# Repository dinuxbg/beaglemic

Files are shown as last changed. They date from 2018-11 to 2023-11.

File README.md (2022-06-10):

# BeagleMic 16-channel PDM Audio Capture

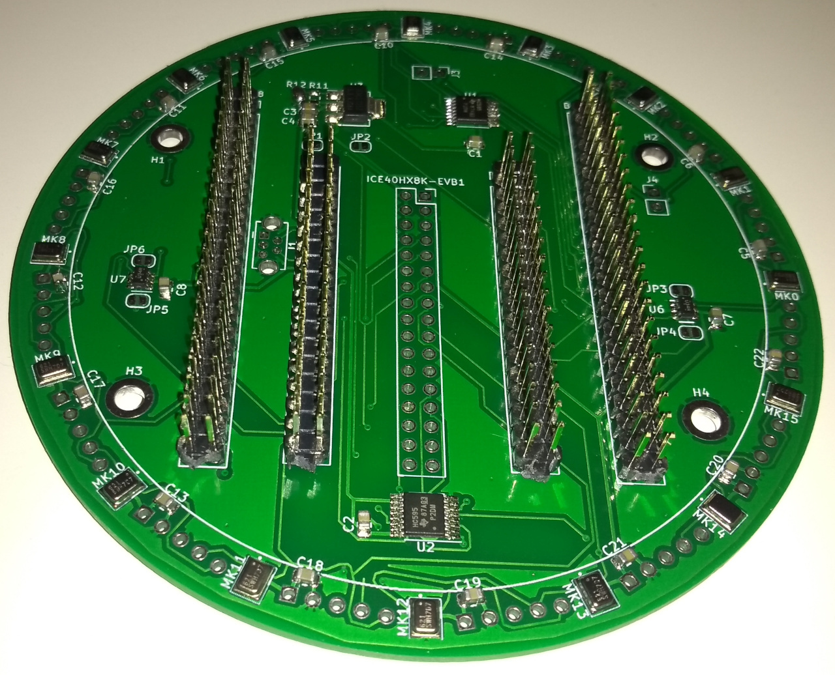
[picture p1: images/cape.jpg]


# Introduction
Ever wanted to record audio from 16 PDM microphones simultanously? Now you can with a BeagleMic running on a [PocketBeagle](https://beagleboard.org/pocket) or [BeagleBone AI](https://bbb.io/ai)

Yes, you could opt for the much simpler I2S microphones. But then you won't have fun writing assembly to capture and process sixteen digital signals at more than 2MHz sample rate.

Audio can be routed to BeagleBone's USB gadget driver. Multichannel audio data can be recorded from a regular PC just as you would record from any other USB microphone. See the section about Buildroot image below.

Current firmware supports:

| Feature | 16 Channel Mode | 8 Channel Mode |
|---|---|---|
| PDM Bit Clock | 2,273 MHz | 3,448 MHz |
| PCM Output Bits Per Sample | 16 bps | 24 bps |
| PCM Output Sample Rate | 31888 Samples/sec | 26940 Samples/sec |

# Freedom
To the best of my knowledge, the entire HW design is Open Hardware and designed with the libre KiCad software. The entire firmware stack is free software, and is built by free toolchains.

Please report any closed components you notice.

# Hardware
The schematic is simple. PDM microphones' digital outputs are connected directly to the PRU input pins. The PRU also drives the bit clock. I have tested on PocketBeagle and BeagleBone AI.

| PocketBeagle | BBAI  | PRU Pin | Type  | Signal |
|---|---|---|---|---|
| P2.24 | P9.11 | R30_14  | Output| PDM Bit Clock |
| P1.36 | P8.44 | R31_0 | Input | MIC0 and MIC1 Data |
| P1.33 | P8.41 | R31_1 | Input | MIC2 and MIC3 Data |
| P2.32 | P8.42 | R31_2 | Input | MIC4 and MIC5 Data |
| P2.30 | P8.39 | R31_3 | Input | MIC6 and MIC7 Data |
| P1.31 | P8.40 | R31_4 | Input | MIC8 and MIC9 Data |
| P2.34 | P8.37 | R31_5 | Input | MIC10 and MIC11 Data |
| P2.28 | P8.38 | R31_6 | Input | MIC12 and MIC13 Data |
| P1.29 | P8.36 | R31_7 | Input | MIC14 and MIC15 Data |

Optionally, high-level software may visualize detected audio direction using a stripe of 16 LEDs hooked to two 74HC595 shift registers:

| PocketBeagle | PB GPIO  | BBAI  | BBAI GPIO | Signal |
|---|---|---|---|---|
| P2.25 | gpio2_9  | P9.30 | gpio5_12  | DS |
| P2.29 | gpio1_7  | P9.28 | gpio4_17  | SHCP |
| P2.31 | gpio1_19 | P9.23 | gpio7_11  | STCP |

For each microphone pair, one microphone is configured to output data on the rising clock edge, and the other is configured to output data on the falling edge. This way we need only 8 input GPIOs to capture data from all 16 microphones.

Microphone breakout board and a PocketBeagle Cape are provided in KiCad format.

Unfortunately the breakout board is essential for a home DIY user like me, since all PDM microphones I could find are BGA. There are numerous youtube guides how to solder BGAs at home using a skillet or a toaster oven.

# Software
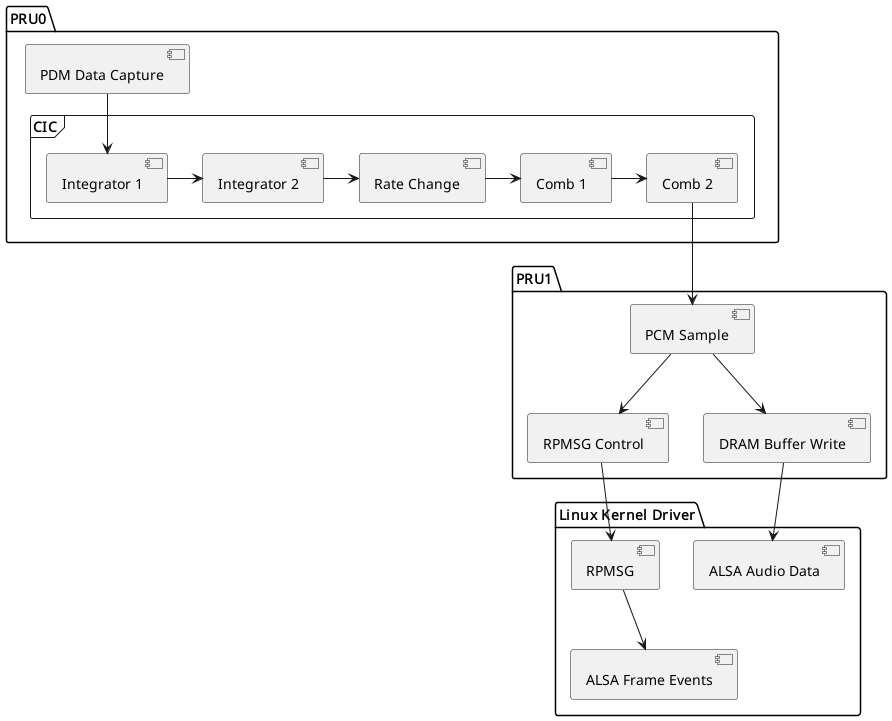
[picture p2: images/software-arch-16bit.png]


PRU0 takes care of driving the PDM bit clock and capturing the microphone bit data. It then runs a CIC filter to convert PDM to PCM, and feeds PCM data to PRU1.

PRU0 has two alternative modes of operation. For 16 channels it executes 2 integrator and 2 comb stages for CIC filtering. Whereas for 8 channels it does 3.

PRU1 is retransmitting PCM data from PRU0 down to the ARM host. RPMSG is used for control commands. Shared DDRAM buffers are used for audio data.

Host audio driver presents a standard ALSA audio card, so that arecord and other standard tools can be readily used.

# Running The Example on PocketBeagle

    # Build kernel module
    sudo apt update
    sudo apt install build-essential linux-headers-`uname -r`
    cd driver
    make
    # Install kernel module
    sudo cp beaglemic.ko /lib/modules/`uname -r`/kernel/drivers/rpmsg/
    sudo depmod -a

    # Load the driver
    sudo modprobe beaglemic

    # Build PRU firmware
    cd pru
    make
    # Start the new PRU firmware
    sudo ./start.sh

    # Record audio
    arecord  -r31888  -c16 -f S16_LE -t wav out.wav
    arecord  -r26940  -c8 -f S32_LE -t wav out.wav
    # Hit Ctrl+C to stop.

# Running The Example on BeagleBone AI

    # Prebuilt DTBO for BB AI is provided in this repo. For corresponding
    # source change, see driver/0001-Initial-BeagleMic-DTS-for-BBAI.patch
    sudo cp driver/am5729-beagleboneai-beaglemic.dtb /boot/dtbs/`uname -r`/
    sudo sed -i -e 's@#dtb=@dtb=am5729-beagleboneai-beaglemic.dtb@g' /boot/uEnv.txt
    sync
    sudo reboot

    # Build kernel module
    sudo apt update
    sudo apt install build-essential linux-headers-`uname -r`
    cd driver
    make
    # Install kernel module
    sudo cp beaglemic.ko /lib/modules/`uname -r`/kernel/drivers/rpmsg/
    sudo depmod -a

    # Load the driver
    sudo modprobe beaglemic

    # Build PRU firmware
    cd pru
    make
    # Start the new PRU firmware
    sudo ./start-bbai.sh

    # Record audio. Use second audio card, since first one is
    # the onboard HDMI.
    arecord -D hw:CARD=BeagleMic -r31888  -c16 -f S16_LE -t wav out.wav
    arecord -D hw:CARD=BeagleMic -r26940  -c8 -f S32_LE -t wav out.wav
    # Hit Ctrl+C to stop.

# Folder Structure

 * beaglemic-cape - Universal cape for BeagleBone AI, PocketBeagle and iCE40HX8K-EVB.
 * driver - Host ALSA audio driver.
 * inmp621-breakout - INMP621 Microphone breakout. Designed to be optionally used with beaglemic-cape.
 * libs - Library code. Currently contains code to drive LED ring for beaglemic-cape.
 * pru - PRU firmware.

# Further Work
A few ideas to improve the design:

 * Move comb filters to PRU1, and try to add more integrators in PRU0.
 * Clean-up the cape PCB.
   * If possible, leave headers for Class-D output from spare PRUs.
 * Migrate to latest kernel 5.10.

# Buildroot Image With USB UAC2 Gadget Mode
The above installation and build instruction steps can be daunting. A [buildroot](https://buildroot.org) configuration for PocketBeagle is available to automate them, and add a bit more.

The buildroot image is small (about 6MB). It initializes the BeagleMic audio driver, and links it to the UAC2 USB Gadget driver. Your BeagleMic PocketBeagle is presented as USB multichannel microphone, so that a regular PC can capture and run desired audio algorithms.

You need to download the beaglemic and buildroot.org GIT trees in separate directories. Then, when building from the buildroot directory you need to provide the beaglemic path via BR2_EXTERNAL environment variable. Example commands:

	git clone --depth=1 git://git.busybox.net/buildroot
	git clone --depth=1 https://gitlab.com/dinuxbg/beaglemic

	cd buildroot
	git checkout 2021.05.3  # Last BR release with kernel 4.19
	export BR2_EXTERNAL=`realpath ../beaglemic/buildroot/`
	make beaglemic_pb_defconfig
	make -j`nproc`

Above should result in a small SDCard image which you can flash. Be sure to get the /dev/sdX right for your SD/MMC card reader.

	sudo dd if=output/images/sdcard.img of=/dev/sdX

When PocketBeagle boots and you connect it via USB to your host, you should be able to record:

	arecord -D hw:CARD=BeagleMic -c8 -t wav -f S32_LE -r24000 out-8ch.wav

## Audio Mode Configuration
Right now UAC2 Gadget is configured only for 8ch/32bps/24000kHz. With a few manual tweaks in buildroot/package/beaglemic-firmware/beaglemicd it can be switched to 16ch/16bps mode. I'm currently researching how I can make this configuration run-time, and how I can control the LED ring via USB.

# References
 * [CIC Filter Introduction](https://dspguru.com/dsp/tutorials/cic-filter-introduction/)
 * [Another CIC Filter Article](http://www.tsdconseil.fr/log/scriptscilab/cic/cic-en.pdf)
 * [Series of PDM articles and software implementations](https://curiouser.cheshireeng.com/category/projects/pdm-microphone-toys/)
 * [Another CIC Filter Article](https://www.embedded.com/design/configurable-systems/4006446/Understanding-cascaded-integrator-comb-filters)
 * [CIC Filter Introduction](http://home.mit.bme.hu/~kollar/papers/cic.pdf)
 * [SPM0423HD4H Datasheet](http://media.digikey.com/PDF/Data%20Sheets/Knowles%20Acoustics%20PDFs/SPM0423HD4H-WB.pdf)
 * [INMP621 Datasheet](https://invensense.tdk.com/download-pdf/inmp621-datasheet/)
 * [Inspiration for high-bandwidth data acquisition](https://github.com/ZeekHuge/BeagleScope)

# Other Resources
Below are various other CIC implementations and PDM microphone boards I've stumbled upon.
 * https://github.com/introlab/16SoundsUSB
 * https://github.com/introlab/odas
 * https://respeaker.io/make_a_smart_speaker/
 * https://github.com/Scrashdown/PRU-Audio-Processing
 * https://github.com/fakufaku/kurodako

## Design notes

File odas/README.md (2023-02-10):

This is a sample configuration for running [ODAS](https://github.com/introlab/odas) with BeagleMic.

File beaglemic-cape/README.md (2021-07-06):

# Beaglemic-Cape

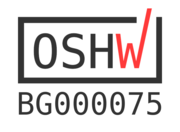
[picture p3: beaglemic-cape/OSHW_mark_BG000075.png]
OSHW


This is a KiCAD project for a 16 PDM Microphone board with host support for:
 * BeagleBone AI
 * PocketBeagle
 * ICE40HX8K-EVB1 (**untested!**)

PDM microphones can either be:
 * Soldered on the cape board, which is not for beginners. You would require a steady hand or pick-and-place machine, and reflow soldering oven.
 * Connected via regular headers using external [breakout](../inmp621-breakout/README.md) [board](https://www.adafruit.com/product/3492).

# Future Improvements

A few ideas for improvements in an eventual future PCB revision:

 * Move the USB OTG connector to the outer edge, so that cable does not interfere with PocketBeagle.
 * Add a few extra LEDs for power and other status.
 * Add better package placement indicators on silkscreen (e.g. first pin, IC dent).
 * Remove the BBAI connector. I couldn't find a way to utilize the proprietary DSPs, so let's focus on USB microphone with PocketBeagle.
 * Switch to bottom-facing LEDs so that all SMD parts are on one of the PCB sides.

# References
 * Microphone footprint, 3D model and schematics symbol are taken from https://www.snapeda.com/parts/INMP621/InvenSense/view-part/?ref=digikey . Footprint has minor modification to "break" the ground track and ease the data wires routing.
 * Freerouting.org was used for routing some of the PCB tracks.

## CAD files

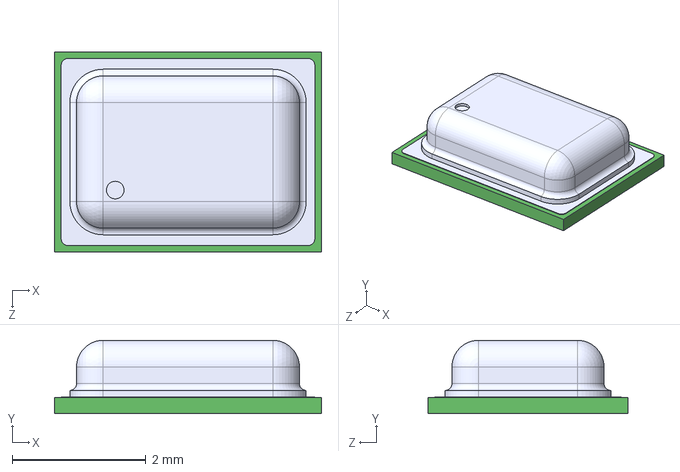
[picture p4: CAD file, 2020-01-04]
beaglemic-cape/INMP621--3DModel-STEP-56544.STEP
4.00 x 1.10 x 3.00 mm

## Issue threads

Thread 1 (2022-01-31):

How to interface I2S mic?

mculla95, 2022-01-31:
Hello

@dinuxbg you mention that interfacing an I2S mic would be much easier, however I am trying to do so but I am having problems. I have a Beaglebone AI and a [TIDA-01454](https://www.ti.com/tool/TIDA-01454) which outputs in I2S. I followed this [guide](https://community.element14.com/challenges-projects/project14/visionthing/b/blog/posts/beaglebone-ai-survival-guide-v3-18-pwm-i2c-analog-digital-read-write-vision-ai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) for pinmuxing and tried to follow [this one](https://www.ti.com/lit/an/sprac97/sprac97.pdf) from TI for the codec. The soundcard is detected however when I try to record i get this error:

```
debian@beaglebone:/var/lib/cloud9$ arecord --device="hw:1,0" -d 20 -f S16_LE test.wav
Recording WAVE 'test.wav' : Signed 16 bit Little Endian, Rate 8000 Hz, Mono
arecord: pcm_read:2145: read error: Input/output error
```

I cant exactly copy the dts file in TI guide because mcasp1_fck isnt defined in Beaglebone AI. So how would I have to interface the codec in the DTS file?

This is my DTS file right now:

```
#include "am5729-beagleboneai.dts"
// make it easy to determine which dtb you're currently running on
// (via /proc/device-tree/chosen/)
/ {
 chosen {
  base_dtb = "am5729-beagleboneai-custom.dts";
  base_dtb_timestamp = __TIMESTAMP__;
 };
};
// eventually these should be available in a header
#define P9_14  (0x3400 + 4 * 107)
#define P9_16  (0x3400 + 4 * 108)
#define P9_19a (0x3400 + 4 * 16)
#define P9_19b (0x3400 + 4 * 95)
#define P9_20a (0x3400 + 4 * 17)
#define P9_20b (0x3400 + 4 * 94)
#define P9_12  (0x3400 + 4 * 171)
#define P9_27b (0x3400 + 4 * 172)
#define P9_18b (0x3400 + 4 * 173)
//
/{

pcm5102a: pcm5102a {
   #sound-dai-cells = <0>;
   compatible = "ti,pcm5102a";
   status = "okay";
};

sound {compatible = "simple-audio-card";
        simple-audio-card,format = "i2s";
        simple-audio-card,name = "PCM5102a";
        simple-audio-card,bitclock-master = <&sound1_master>;
        simple-audio-card,frame-master = <&sound1_master>;
        simple-audio-card,bitclock-inversion;

        simple-audio-card,cpu {
                sound-dai = <&mcasp1>;
        };
        sound1_master: simple-audio-card,codec {
            #sound-dai-cells = <0>;
            sound-dai = <&pcm5102a>;
    
        };
      };
};

// enable i2c-3 on P9.19 (scl) + P9.20 (sda)
&i2c4 {
 status = "okay";
 clock-frequency = <400000>;
 pinctrl-names = "default";
 pinctrl-0 = <&i2c4_pins>;

};

&mcasp1 {
    #sound-dai-cells = <0>;
    status = "okay";
    pinctrl-names = "default";
    pinctrl-0 = <&mcasp1_pins>;
    op-mode = <0>;    /* MCASP_IIS_MODE */
    tdm-slots = <2>;
    num-serializer = <4>;
    /* 16 serializers */
    serial-dir = < /* 1 TX 2 RX 0 unused */
             2 0 0 0
        >;
    rx-num-evt = <1>;
    tx-num-evt = <1>;
};

&dra7_pmx_core {
 i2c4_pins: i2c4 {
  pinctrl-single,pins = <
   DRA7XX_CORE_IOPAD( P9_19a, PIN_INPUT_PULLUP | MUX_MODE7  )  // scl
   DRA7XX_CORE_IOPAD( P9_19b, PIN_INPUT_PULLUP | MUX_MODE14 )  // (shared pin)
   DRA7XX_CORE_IOPAD( P9_20a, PIN_INPUT_PULLUP | MUX_MODE7  )  // sda
   DRA7XX_CORE_IOPAD( P9_20b, PIN_INPUT_PULLUP | MUX_MODE14 )  // (shared pin)
  >;
 };
 mcasp1_pins: mcasp1_pins {
  pinctrl-single,pins = <
   DRA7XX_CORE_IOPAD(P9_12, PIN_INPUT_PULLDOWN | MUX_MODE0) // 12 0  mcasp1_aclkr  BIT CLOCK      BCLK
   DRA7XX_CORE_IOPAD(P9_27b, PIN_INPUT | MUX_MODE0) // 27b 0  mcasp1_fsr    FRAME SYNC            LRCLK
   DRA7XX_CORE_IOPAD(P9_18b, PIN_INPUT | MUX_MODE0) // 18b 0  mcasp1_axr0   I2S INPUT             DATA
  >;
 };
};
// enable pwm-2 on P9.14 (out-A) + P9.16 (out-B)
&epwmss2 {
 status = "okay";
};
&ehrpwm2 {
 status = "okay";
 pinctrl-names = "default";
 pinctrl-0 = <&ehrpwm2_pins>;
};
&dra7_pmx_core {
 ehrpwm2_pins: ehrpwm2 {
  pinctrl-single,pins = <
   DRA7XX_CORE_IOPAD( P9_14, PIN_OUTPUT_PULLDOWN | MUX_MODE10 )  // out A
   DRA7XX_CORE_IOPAD( P9_16, PIN_OUTPUT_PULLDOWN | MUX_MODE10 )  // out B
  >;
 };
};

// Here's the obnoxious part: since u-boot doesn't have same pin defaults yet, all pins not
// explicitly setup above should be overridden here.  This will eventually no longer be needed.
&cape_pins_default {
 pinctrl-single,pins = <
  DRA7XX_CORE_IOPAD( 0x372C, PIN_INPUT_PULLDOWN | MUX_MODE15 ) // P9.11a (no gpio)
  DRA7XX_CORE_IOPAD( 0x3620, PIN_INPUT          | MUX_MODE14 ) // P9.11b
  //DRA7XX_CORE_IOPAD( 0x36AC, PIN_INPUT_PULLDOWN | MUX_MODE14 ) // P9.12
  DRA7XX_CORE_IOPAD( 0x3730, PIN_INPUT_PULLDOWN | MUX_MODE15 ) // P9.13  (no gpio)
 // DRA7XX_CORE_IOPAD( 0x35AC, PIN_INPUT_PULLDOWN | MUX_MODE14 ) // P9.14
  DRA7XX_CORE_IOPAD( 0x3514, PIN_INPUT_PULLDOWN | MUX_MODE14 ) // P9.15
 // DRA7XX_CORE_IOPAD( 0x35B0, PIN_INPUT_PULLDOWN | MUX_MODE14 ) // P9.16
  DRA7XX_CORE_IOPAD( 0x37CC, PIN_INPUT_PULLDOWN | MUX_MODE14 ) // P9.17a
  DRA7XX_CORE_IOPAD( 0x36B8, PIN_INPUT          | MUX_MODE14 ) // P9.17b
  DRA7XX_CORE_IOPAD( 0x37C8, PIN_INPUT_PULLDOWN | MUX_MODE14 ) // P9.18a
  //DRA7XX_CORE_IOPAD( 0x36B4, PIN_INPUT          | MUX_MODE14 ) // P9.18b
 // DRA7XX_CORE_IOPAD( 0x3440, PIN_INPUT_PULLUP   | MUX_MODE14 ) // P9.19a
 // DRA7XX_CORE_IOPAD( 0x357C, PIN_INPUT          | MUX_MODE14 ) // P9.19b
 // DRA7XX_CORE_IOPAD( 0x3444, PIN_INPUT_PULLUP   | MUX_MODE14 ) // P9.20a
 // DRA7XX_CORE_IOPAD( 0x3578, PIN_INPUT          | MUX_MODE14 ) // P9.20b
  DRA7XX_CORE_IOPAD( 0x34F0, PIN_INPUT_PULLDOWN | MUX_MODE14 ) // P9.21a
  DRA7XX_CORE_IOPAD( 0x37C4, PIN_INPUT          | MUX_MODE14 ) // P9.21b
  DRA7XX_CORE_IOPAD( 0x369C, PIN_INPUT_PULLDOWN | MUX_MODE14 ) // P9.22a
  DRA7XX_CORE_IOPAD( 0x37C0, PIN_INPUT          | MUX_MODE14 ) // P9.22b
  DRA7XX_CORE_IOPAD( 0x37B4, PIN_INPUT_PULLUP   | MUX_MODE14 ) // P9.23
  DRA7XX_CORE_IOPAD( 0x368C, PIN_INPUT_PULLUP   | MUX_MODE14 ) // P9.24
  DRA7XX_CORE_IOPAD( 0x3694, PIN_INPUT_PULLDOWN | MUX_MODE14 ) // P9.25
  DRA7XX_CORE_IOPAD( 0x3688, PIN_INPUT_PULLUP   | MUX_MODE14 ) // P9.26a
  DRA7XX_CORE_IOPAD( 0x3544, PIN_INPUT          | MUX_MODE14 ) // P9.26b
  DRA7XX_CORE_IOPAD( 0x35A0, PIN_INPUT_PULLDOWN | MUX_MODE14 ) // P9.27a
  //DRA7XX_CORE_IOPAD( 0x36B0, PIN_INPUT          | MUX_MODE14 ) // P9.27b
  DRA7XX_CORE_IOPAD( 0x36E0, PIN_INPUT_PULLDOWN | MUX_MODE14 ) // P9.28
  DRA7XX_CORE_IOPAD( 0x36D8, PIN_INPUT_PULLDOWN | MUX_MODE14 ) // P9.29a
  DRA7XX_CORE_IOPAD( 0x36A8, PIN_INPUT          | MUX_MODE14 ) // P9.29b
  DRA7XX_CORE_IOPAD( 0x36DC, PIN_INPUT_PULLDOWN | MUX_MODE14 ) // P9.30
  DRA7XX_CORE_IOPAD( 0x36D4, PIN_INPUT_PULLDOWN | MUX_MODE14 ) // P9.31a
  DRA7XX_CORE_IOPAD( 0x36A4, PIN_INPUT          | MUX_MODE14 ) // P9.31b
  DRA7XX_CORE_IOPAD( 0x36A0, PIN_INPUT_PULLDOWN | MUX_MODE14 ) // P9.41a
  DRA7XX_CORE_IOPAD( 0x3580, PIN_INPUT          | MUX_MODE14 ) // P9.41b
  DRA7XX_CORE_IOPAD( 0x36E4, PIN_INPUT_PULLDOWN | MUX_MODE14 ) // P9.42a
  DRA7XX_CORE_IOPAD( 0x359C, PIN_INPUT          | MUX_MODE14 ) // P9.42b
  DRA7XX_CORE_IOPAD( 0x379C, PIN_INPUT_PULLUP   | MUX_MODE14 ) // P8.3
  DRA7XX_CORE_IOPAD( 0x37A0, PIN_INPUT_PULLUP   | MUX_MODE14 ) // P8.4
  DRA7XX_CORE_IOPAD( 0x378C, PIN_INPUT_PULLUP   | MUX_MODE14 ) // P8.5
  DRA7XX_CORE_IOPAD( 0x3790, PIN_INPUT_PULLUP   | MUX_MODE14 ) // P8.6
  DRA7XX_CORE_IOPAD( 0x36EC, PIN_INPUT_PULLDOWN | MUX_MODE14 ) // P8.7
  DRA7XX_CORE_IOPAD( 0x36F0, PIN_INPUT_PULLDOWN | MUX_MODE14 ) // P8.8
  DRA7XX_CORE_IOPAD( 0x3698, PIN_INPUT_PULLDOWN | MUX_MODE14 ) // P8.9
  DRA7XX_CORE_IOPAD( 0x36E8, PIN_INPUT_PULLDOWN | MUX_MODE14 ) // P8.10
  DRA7XX_CORE_IOPAD( 0x3510, PIN_INPUT_PULLDOWN | MUX_MODE14 ) // P8.11
  DRA7XX_CORE_IOPAD( 0x350C, PIN_INPUT_PULLDOWN | MUX_MODE14 ) // P8.12
  DRA7XX_CORE_IOPAD( 0x3590, PIN_INPUT_PULLDOWN | MUX_MODE14 ) // P8.13
  DRA7XX_CORE_IOPAD( 0x3598, PIN_INPUT_PULLDOWN | MUX_MODE14 ) // P8.14
  DRA7XX_CORE_IOPAD( 0x3570, PIN_INPUT_PULLDOWN | MUX_MODE14 ) // P8.15a
  DRA7XX_CORE_IOPAD( 0x35B4, PIN_INPUT          | MUX_MODE14 ) // P8.15b
  DRA7XX_CORE_IOPAD( 0x35BC, PIN_INPUT_PULLDOWN | MUX_MODE14 ) // P8.16
  DRA7XX_CORE_IOPAD( 0x3624, PIN_INPUT_PULLDOWN | MUX_MODE14 ) // P8.17
  DRA7XX_CORE_IOPAD( 0x3588, PIN_INPUT_PULLDOWN | MUX_MODE14 ) // P8.18
  DRA7XX_CORE_IOPAD( 0x358C, PIN_INPUT_PULLDOWN | MUX_MODE14 ) // P8.19
  DRA7XX_CORE_IOPAD( 0x3780, PIN_INPUT_PULLUP   | MUX_MODE14 ) // P8.20
  DRA7XX_CORE_IOPAD( 0x377C, PIN_INPUT_PULLUP   | MUX_MODE14 ) // P8.21
  DRA7XX_CORE_IOPAD( 0x3798, PIN_INPUT_PULLUP   | MUX_MODE14 ) // P8.22
  DRA7XX_CORE_IOPAD( 0x3794, PIN_INPUT_PULLUP   | MUX_MODE14 ) // P8.23
  DRA7XX_CORE_IOPAD( 0x3788, PIN_INPUT_PULLUP   | MUX_MODE14 ) // P8.24
  DRA7XX_CORE_IOPAD( 0x3784, PIN_INPUT_PULLUP   | MUX_MODE14 ) // P8.25
  DRA7XX_CORE_IOPAD( 0x35B8, PIN_INPUT_PULLDOWN | MUX_MODE14 ) // P8.26
  DRA7XX_CORE_IOPAD( 0x35D8, PIN_INPUT_PULLDOWN | MUX_MODE14 ) // P8.27a
  DRA7XX_CORE_IOPAD( 0x3628, PIN_INPUT          | MUX_MODE14 ) // P8.27b
  DRA7XX_CORE_IOPAD( 0x35C8, PIN_INPUT_PULLDOWN | MUX_MODE14 ) // P8.28a
  DRA7XX_CORE_IOPAD( 0x362C, PIN_INPUT          | MUX_MODE14 ) // P8.28b
  DRA7XX_CORE_IOPAD( 0x35D4, PIN_INPUT_PULLDOWN | MUX_MODE14 ) // P8.29a
  DRA7XX_CORE_IOPAD( 0x3630, PIN_INPUT          | MUX_MODE14 ) // P8.29b
  DRA7XX_CORE_IOPAD( 0x35CC, PIN_INPUT_PULLDOWN | MUX_MODE14 ) // P8.30a
  DRA7XX_CORE_IOPAD( 0x3634, PIN_INPUT          | MUX_MODE14 ) // P8.30b
  DRA7XX_CORE_IOPAD( 0x3614, PIN_INPUT_PULLDOWN | MUX_MODE14 ) // P8.31a
  DRA7XX_CORE_IOPAD( 0x373C, PIN_INPUT_PULLDOWN | MUX_MODE15 ) // P8.31b (no gpio)
  DRA7XX_CORE_IOPAD( 0x3618, PIN_INPUT_PULLDOWN | MUX_MODE14 ) // P8.32a
  DRA7XX_CORE_IOPAD( 0x3740, PIN_INPUT_PULLDOWN | MUX_MODE15 ) // P8.32b (no gpio)
  DRA7XX_CORE_IOPAD( 0x3610, PIN_INPUT_PULLDOWN | MUX_MODE14 ) // P8.33a
  DRA7XX_CORE_IOPAD( 0x34E8, PIN_INPUT          | MUX_MODE14 ) // P8.33b
  DRA7XX_CORE_IOPAD( 0x3608, PIN_INPUT_PULLDOWN | MUX_MODE14 ) // P8.34a
  DRA7XX_CORE_IOPAD( 0x3564, PIN_INPUT          | MUX_MODE14 ) // P8.34b
  DRA7XX_CORE_IOPAD( 0x360C, PIN_INPUT_PULLDOWN | MUX_MODE14 ) // P8.35a
  DRA7XX_CORE_IOPAD( 0x34E4, PIN_INPUT          | MUX_MODE14 ) // P8.35b
  DRA7XX_CORE_IOPAD( 0x3604, PIN_INPUT_PULLDOWN | MUX_MODE14 ) // P8.36a
  DRA7XX_CORE_IOPAD( 0x3568, PIN_INPUT          | MUX_MODE14 ) // P8.36b
  DRA7XX_CORE_IOPAD( 0x35FC, PIN_INPUT_PULLDOWN | MUX_MODE14 ) // P8.37a
  DRA7XX_CORE_IOPAD( 0x3738, PIN_INPUT_PULLDOWN | MUX_MODE15 ) // P8.37b (no gpio)
  DRA7XX_CORE_IOPAD( 0x3600, PIN_INPUT_PULLDOWN | MUX_MODE14 ) // P8.38a
  DRA7XX_CORE_IOPAD( 0x3734, PIN_INPUT_PULLDOWN | MUX_MODE15 ) // P8.38b (no gpio)
  DRA7XX_CORE_IOPAD( 0x35F4, PIN_INPUT_PULLDOWN | MUX_MODE14 ) // P8.39
  DRA7XX_CORE_IOPAD( 0x35F8, PIN_INPUT_PULLDOWN | MUX_MODE14 ) // P8.40
  DRA7XX_CORE_IOPAD( 0x35EC, PIN_INPUT_PULLDOWN | MUX_MODE14 ) // P8.41
  DRA7XX_CORE_IOPAD( 0x35F0, PIN_INPUT_PULLDOWN | MUX_MODE14 ) // P8.42
  DRA7XX_CORE_IOPAD( 0x35E4, PIN_INPUT_PULLDOWN | MUX_MODE14 ) // P8.43
  DRA7XX_CORE_IOPAD( 0x35E8, PIN_INPUT_PULLDOWN | MUX_MODE14 ) // P8.44
  DRA7XX_CORE_IOPAD( 0x35DC, PIN_INPUT_PULLDOWN | MUX_MODE14 ) // P8.45a
  DRA7XX_CORE_IOPAD( 0x361C, PIN_INPUT          | MUX_MODE14 ) // P8.45b
  DRA7XX_CORE_IOPAD( 0x35E0, PIN_INPUT_PULLDOWN | MUX_MODE14 ) // P8.46a
  DRA7XX_CORE_IOPAD( 0x3638, PIN_INPUT          | MUX_MODE14 ) // P8.46b
 >;
};
```

dinuxbg, 2022-01-31:
I'm afraid you cannot reuse anything from beaglemic for your project. McASP configuration is rather different from PRU firmware writing.

By "I2S is simpler" I meant that writing PRU firmware for I2S microphones would be simpler than writing PRU firmware for PDM microphones. Still, it would not be trivial.

I would suggest to play with arecord parameters. Try with "-c2" because I2S is stereo.  Drop the "-d" parameter and let ALSA pick a suitable value. Try other rates besides 8000.

Also it might be better to post this question on the Beagleboard forum.

Closed 2022-01-31.

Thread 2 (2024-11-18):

Port driver to latest TI kernel

dinuxbg, 2024-11-18:
The 4.19 kernel currently used is outdated, forcing the usage of old buildroot for building the linux image. Port to latest kernel - RPMSG is hopefully no longer a fast moving target.

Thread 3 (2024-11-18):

Port to PocketBeagle2

dinuxbg, 2024-11-18:
Port software for the upcoming [PocketBeagle2](https://www.beagleboard.org/boards/pocketbeagle-2), since the original PocketBeagle is no longer in stock.

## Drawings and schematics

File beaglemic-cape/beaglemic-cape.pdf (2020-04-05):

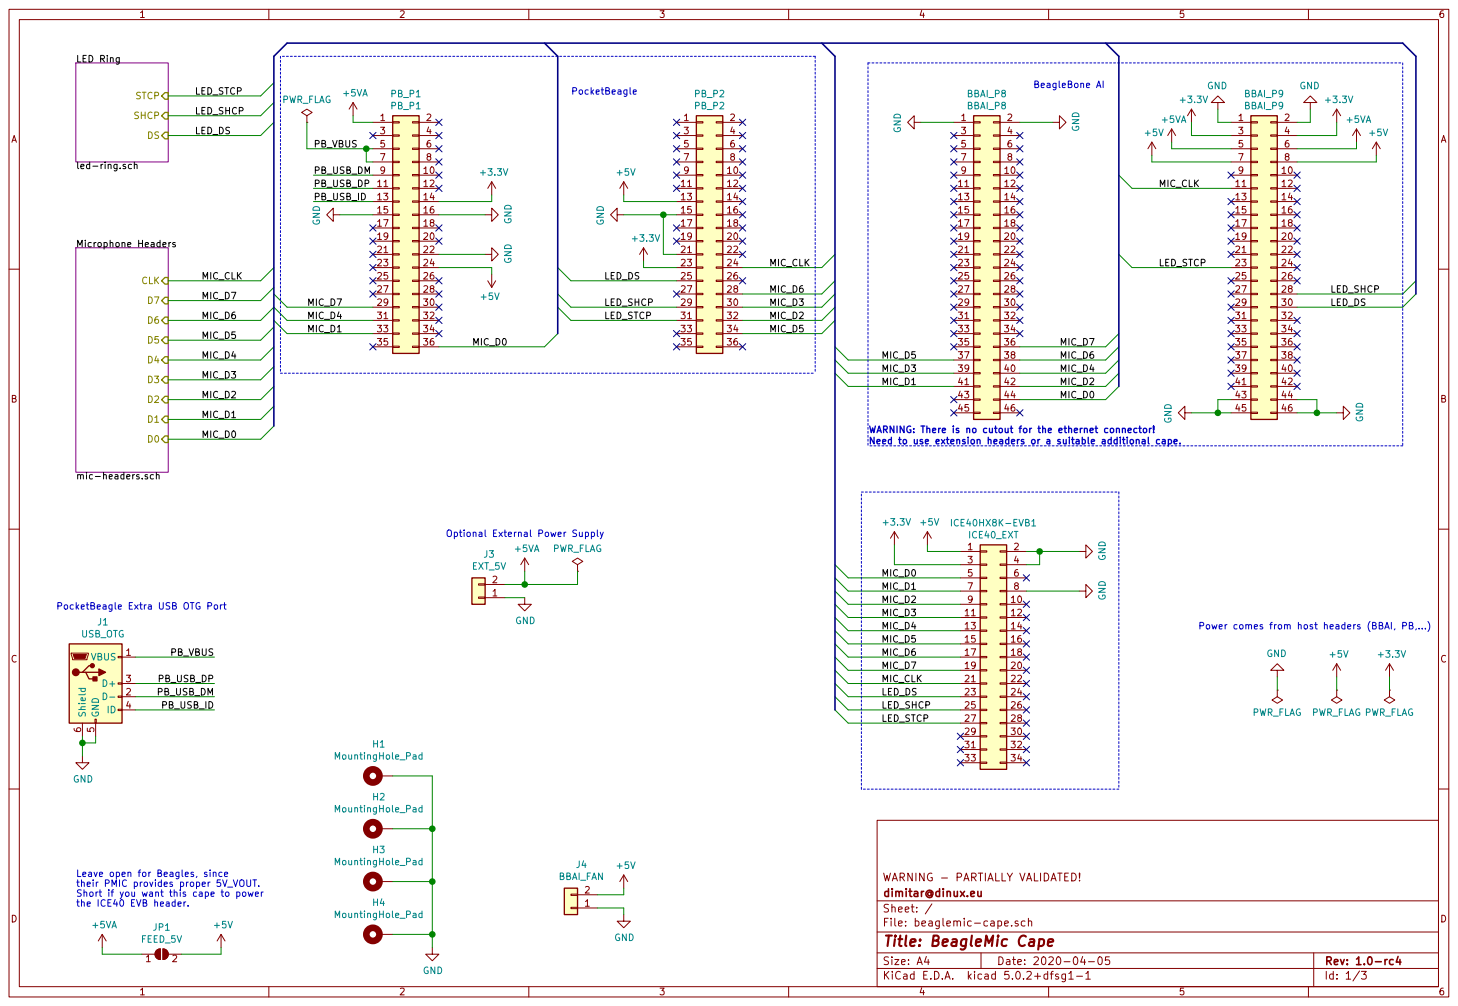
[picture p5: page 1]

Optional External Power Supply +5VA

PocketBeagle Extra USB OTG Port
J1 USB_OTG

Leave open for Beagles, since
their PMIC provides proper 5V_VOUT.
Short if you want this cape to power
the ICE40 EVB header.

File: beaglemic-cape.sch Sheet: / dimitar@dinux.eu WARNING - PARTIALLY VALIDATED!

Id: 1/3 Title: BeagleMic Cape

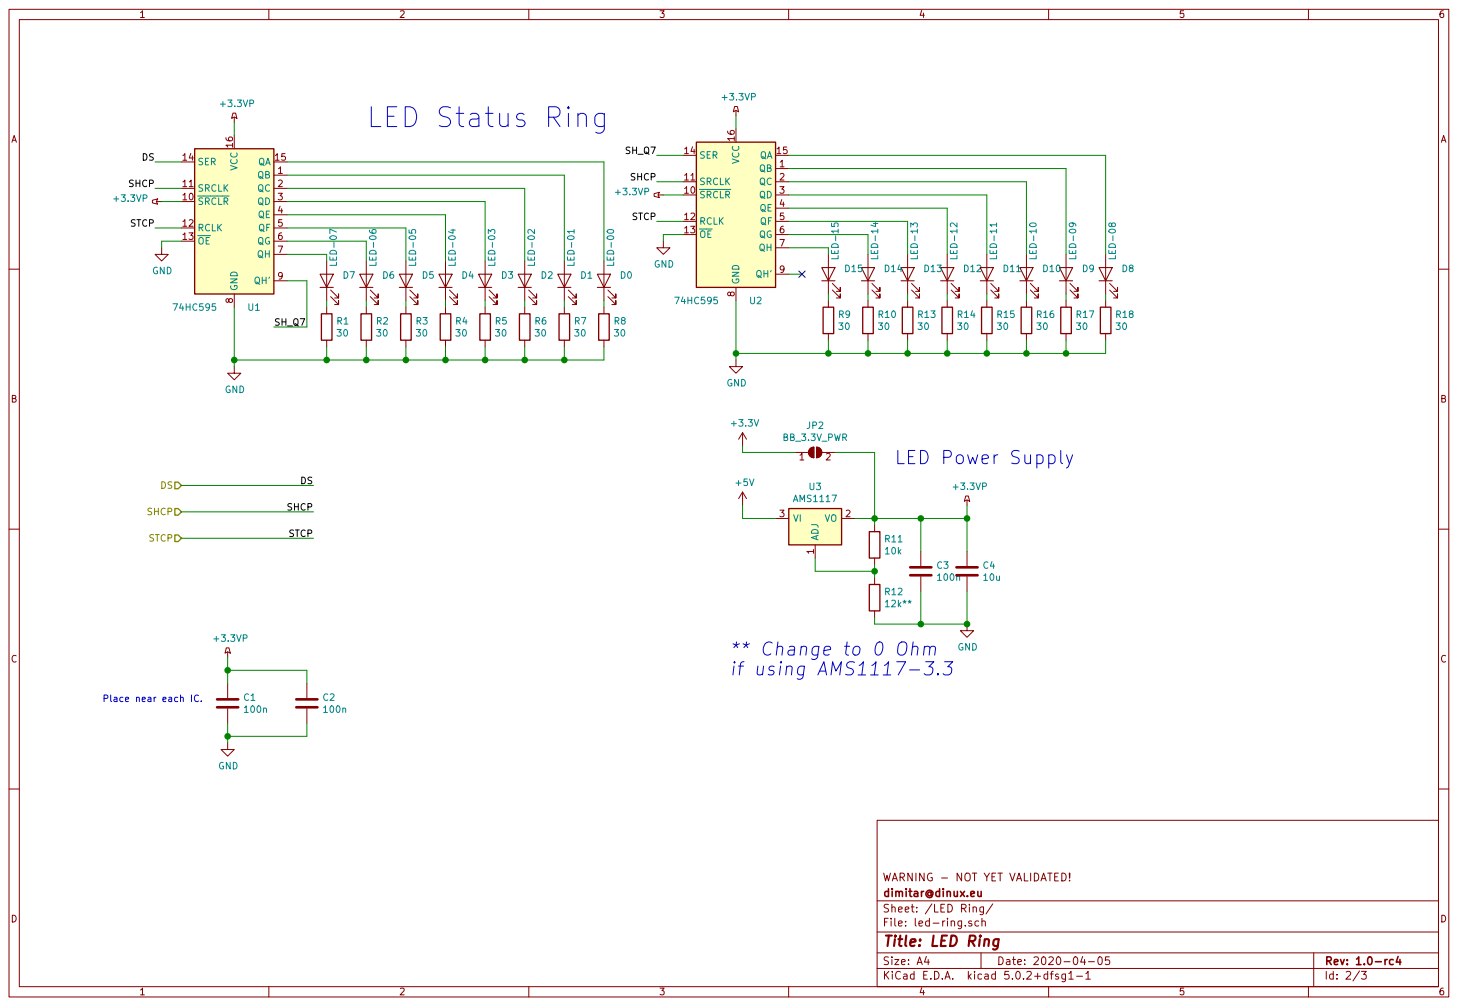
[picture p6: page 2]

dimitar@dinux.eu WARNING - NOT YET VALIDATED!

Sheet: /LED Ring/
File: led-ring.sch
Id: 2/3 Title: LED Ring

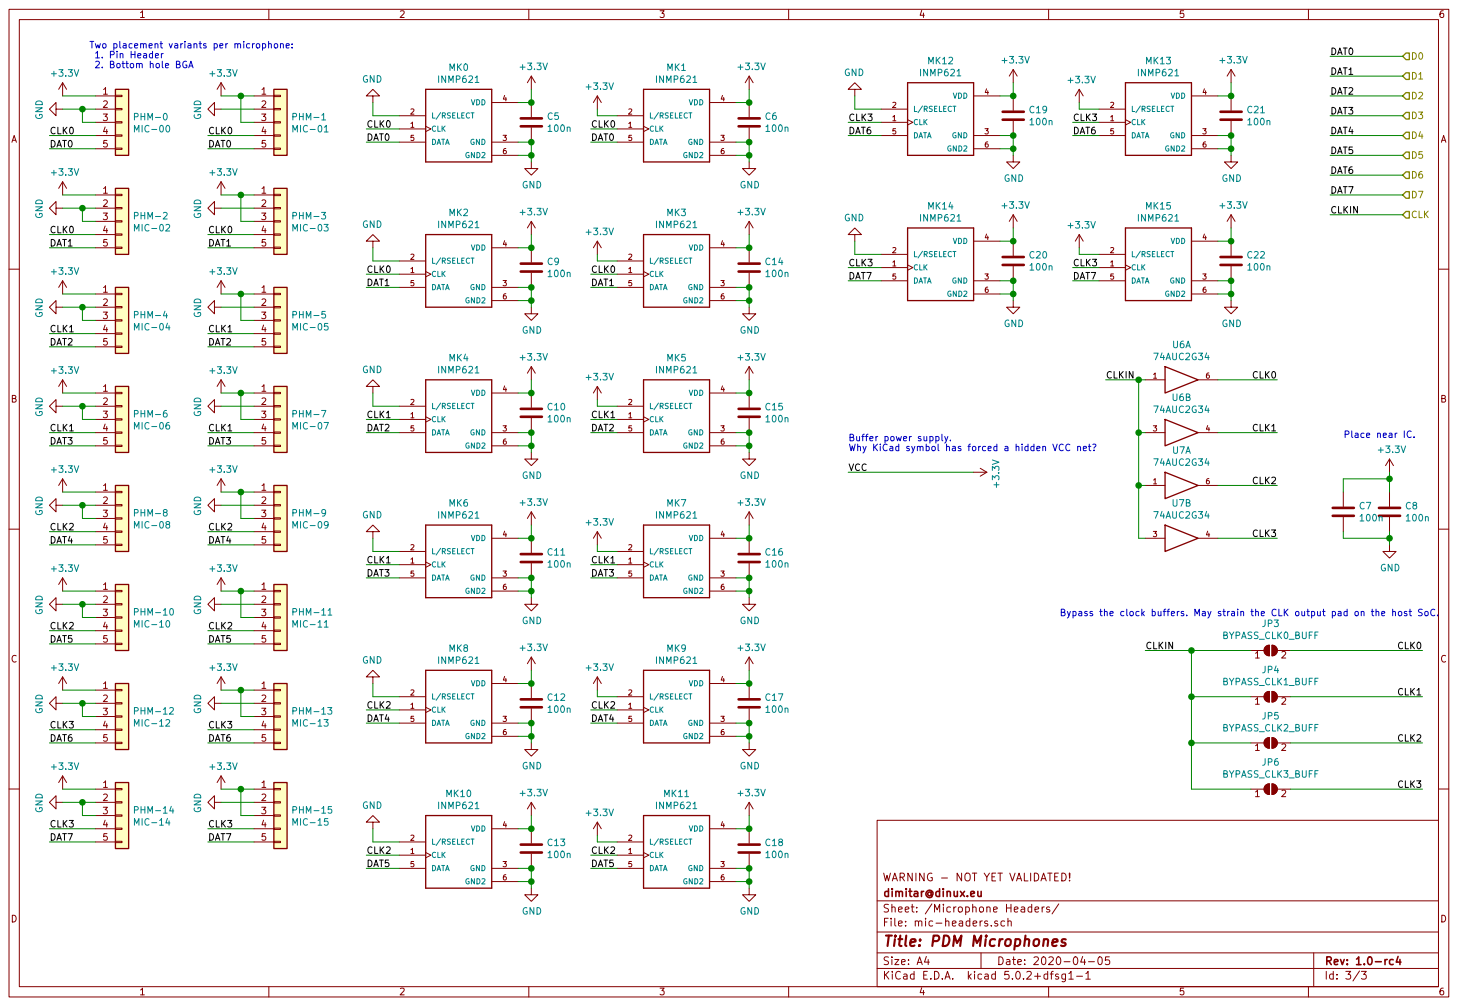
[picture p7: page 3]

Two placement variants per microphone:
1. Pin Header

100n Place near IC. +3.3V GND

File: mic-headers.sch Sheet: /Microphone Headers/
Id: 3/3 Title: PDM Microphones

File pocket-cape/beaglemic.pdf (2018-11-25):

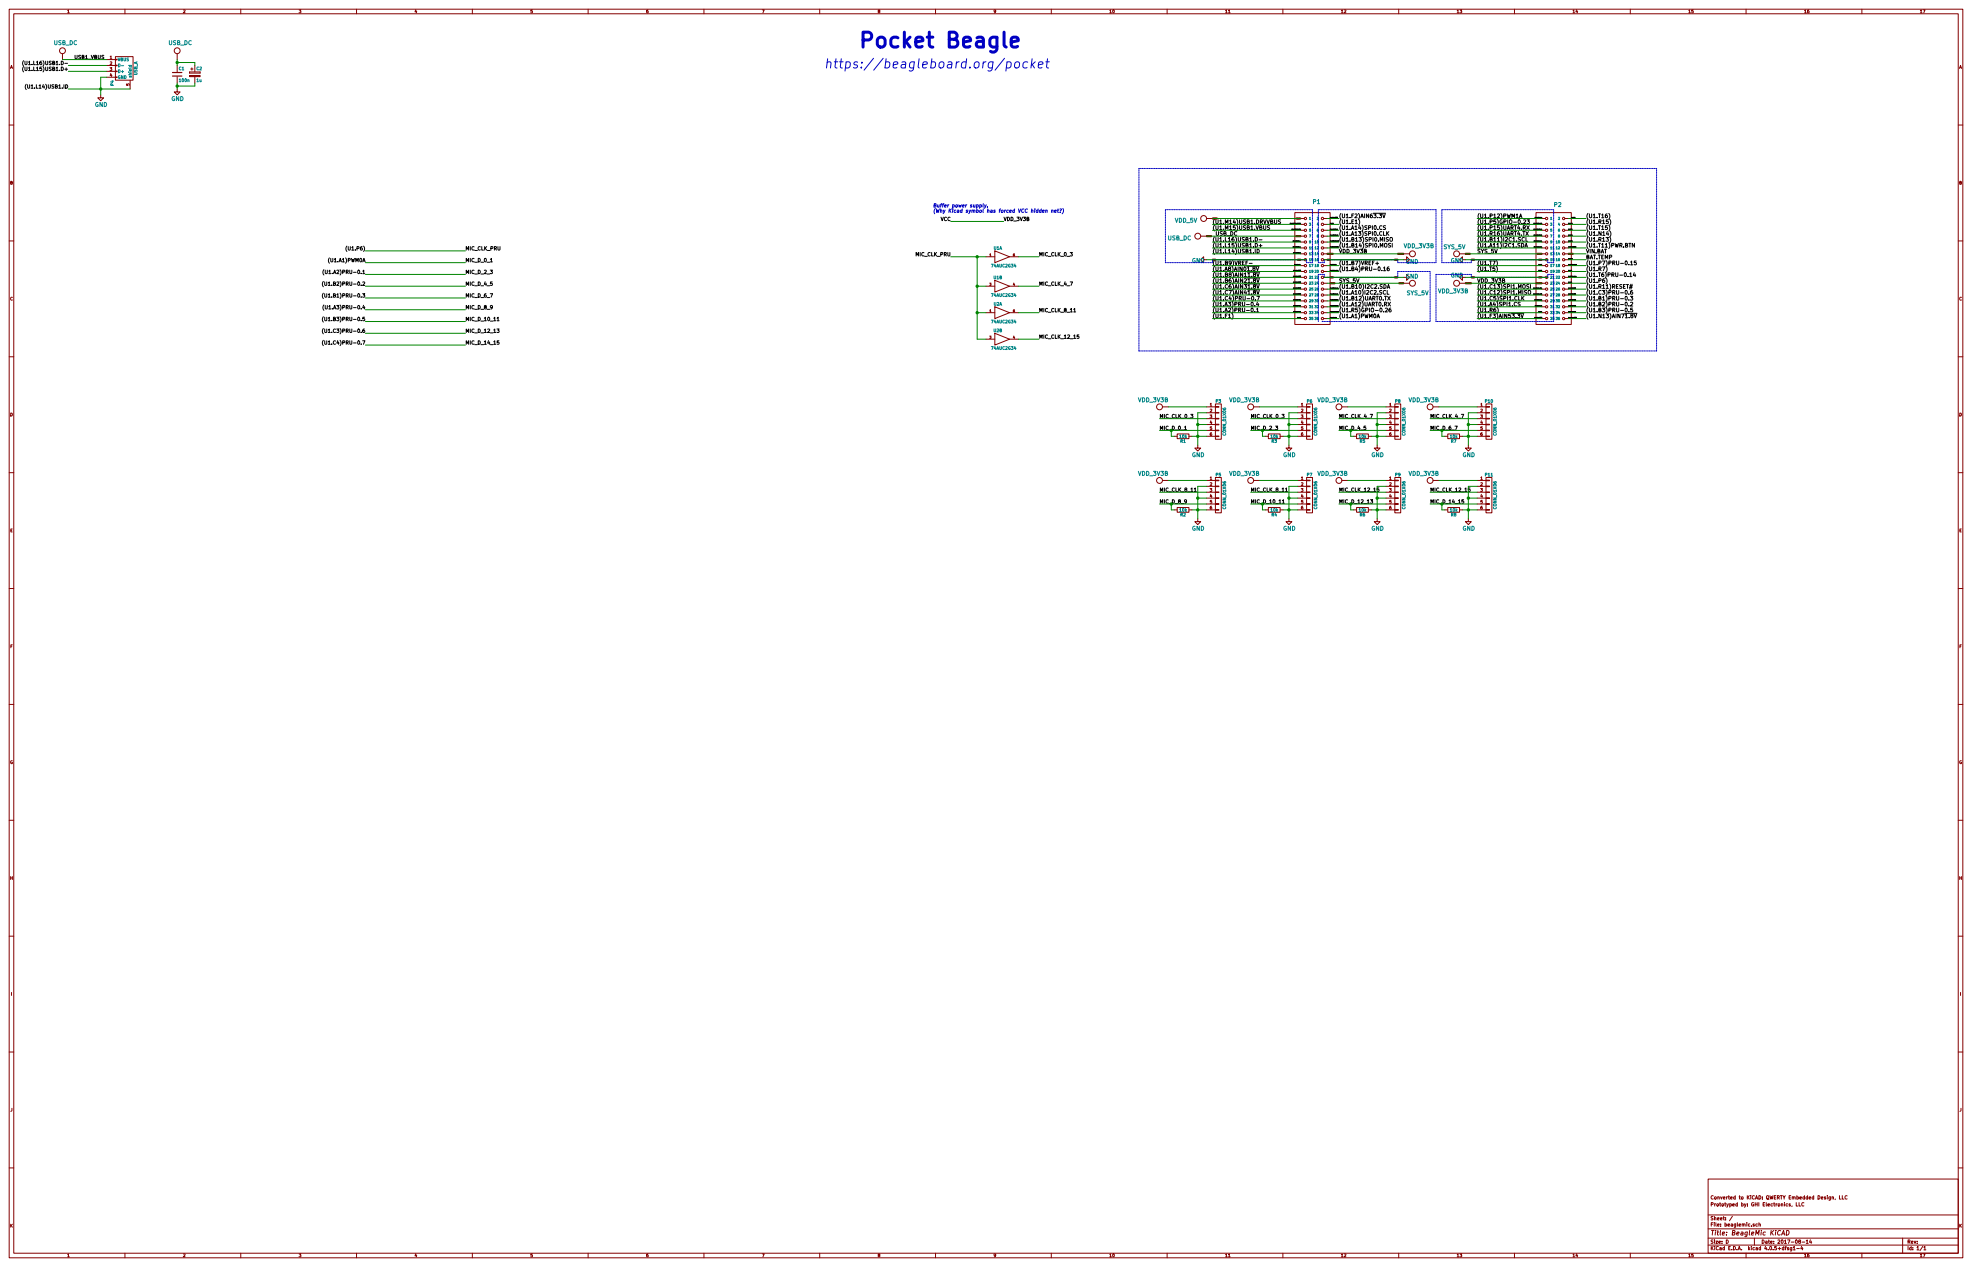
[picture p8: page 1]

VIN.BAT Pocket Beagle
https://beagleboard.org/pocket

Converted to KiCAD: QWERTY Embedded Design, LLC
File: beaglemic.sch Sheet: / Prototyped by: GHI Electronics, LLC

Id: 1/1 Title: BeagleMic KiCAD

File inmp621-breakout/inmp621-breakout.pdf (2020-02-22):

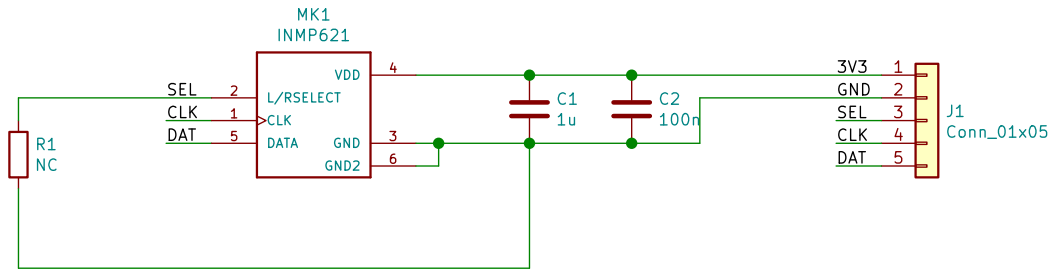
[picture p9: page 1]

3V3 CLK DAT SEL CLK DAT

File: inmp621-breakout.sch Sheet: / dimitar@dinux.eu

Id: 1/1 Title: INMP621 PDM Microphone Breakout

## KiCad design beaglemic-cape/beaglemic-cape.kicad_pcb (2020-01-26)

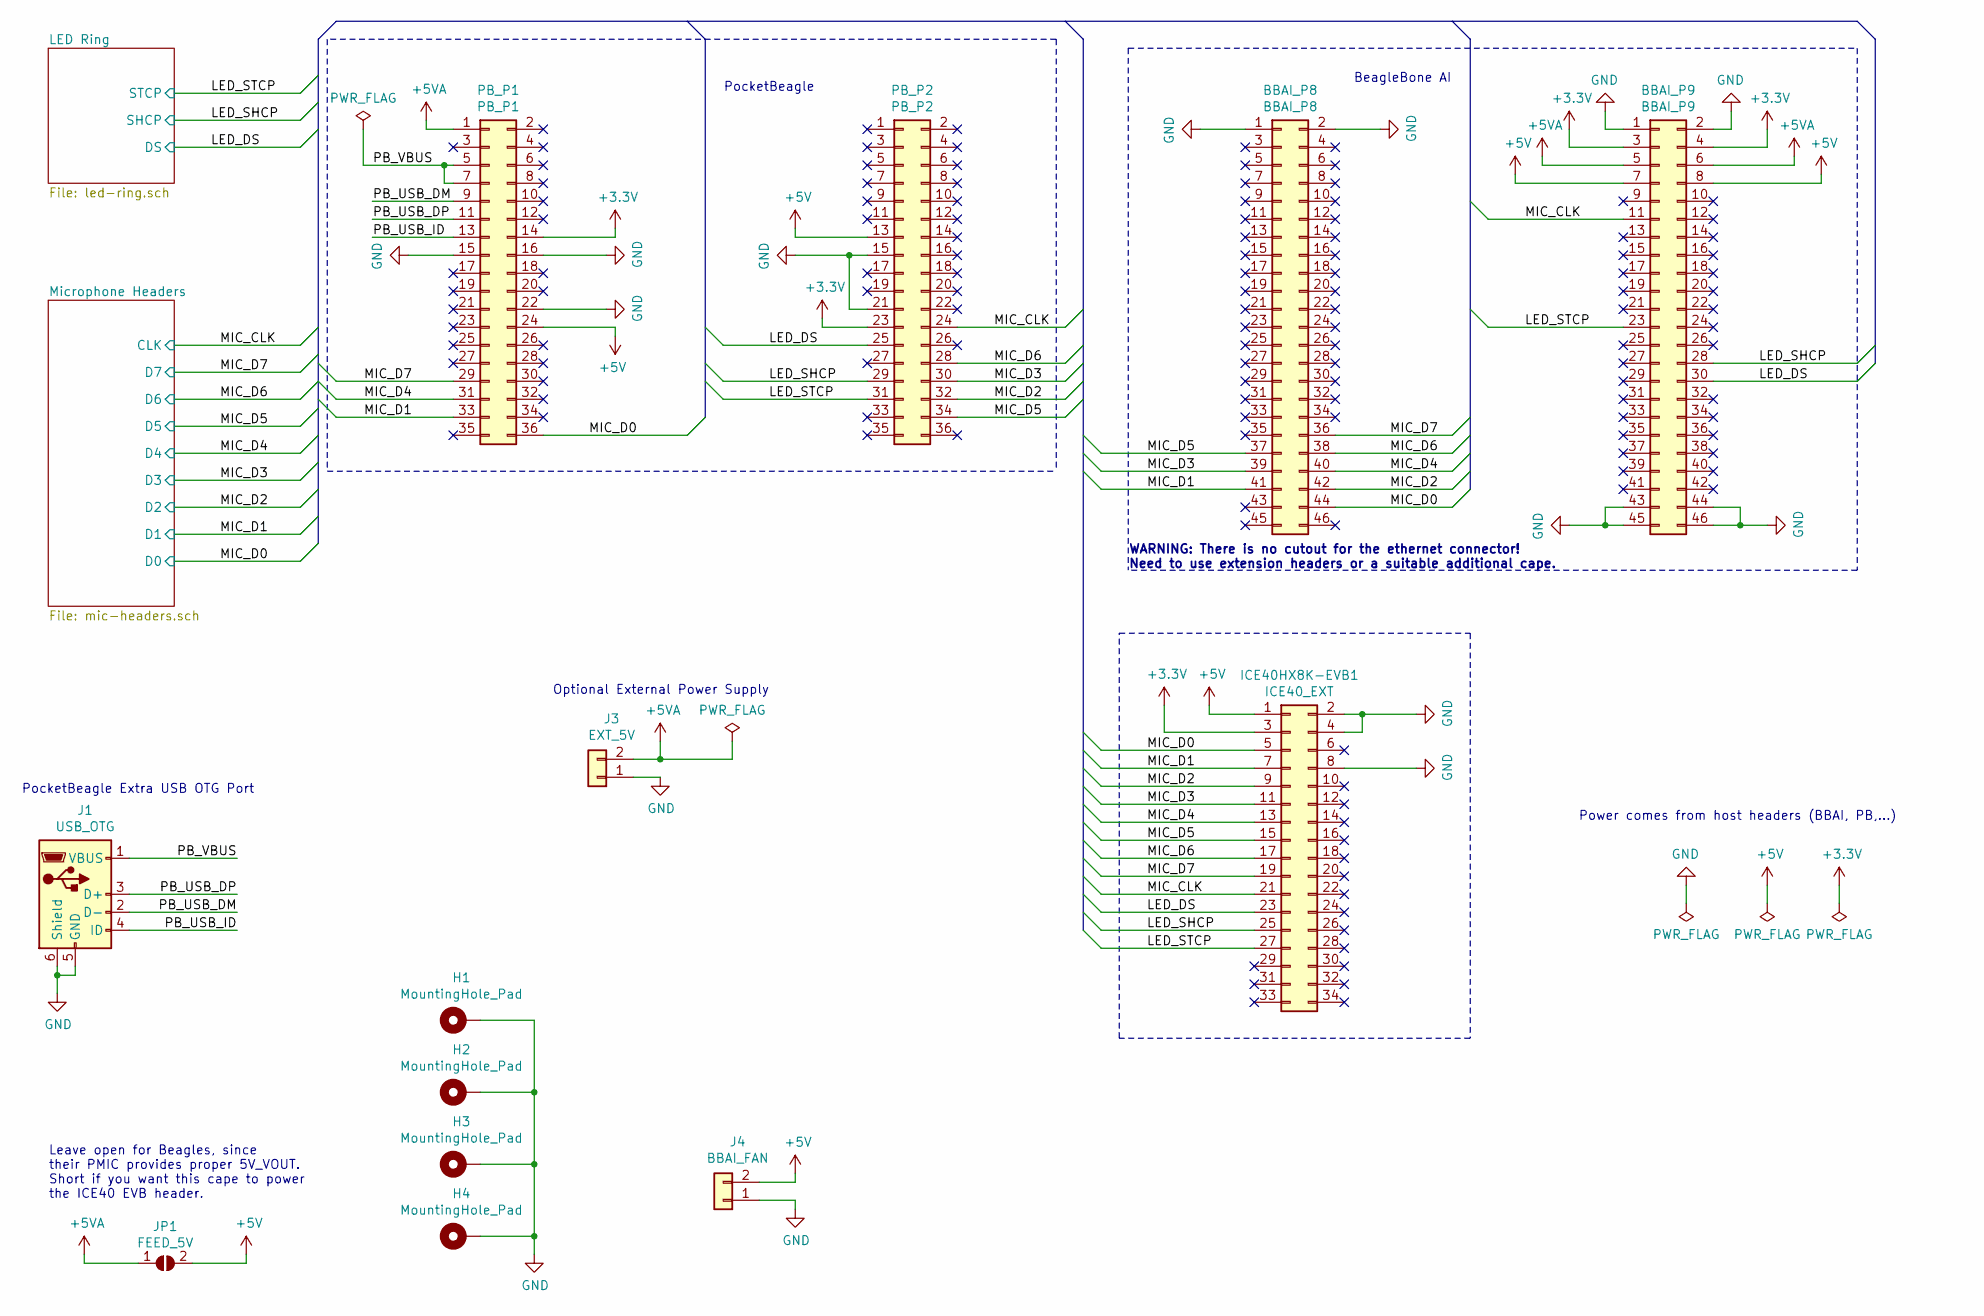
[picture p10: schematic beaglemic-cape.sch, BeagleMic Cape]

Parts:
BBAI_P8: BBAI_P8; PinSocket_2x23_P2.54mm_Vertical
BBAI_P9: BBAI_P9; PinSocket_2x23_P2.54mm_Vertical
H1, H2, H3, H4: MountingHole_Pad; MountingHole_3.2mm_M3_ISO14580_Pad
ICE40HX8K-EVB1: ICE40_EXT; PinSocket_2x17_P2.54mm_Vertical
J1: USB_OTG; USB_Micro-B_Tensility_54-00023_Vertical_CircularHoles
J3: EXT_5V; PinHeader_1x02_P2.54mm_Vertical
J4: BBAI_FAN; PinHeader_1x02_P2.54mm_Vertical
JP1: FEED_5V; SolderJumper-2_P1.3mm_Open_RoundedPad1.0x1.5mm
PB_P1: PB_P1; PinHeader_2x18_P2.54mm_Vertical
PB_P2: PB_P2; PinHeader_2x18_P2.54mm_Vertical

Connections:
+3V3: BBAI_P9.3, BBAI_P9.4, ICE40HX8K-EVB1.3, PB_P1.14, PB_P2.23; also elsewhere on the board
+5V: BBAI_P9.7, BBAI_P9.8, ICE40HX8K-EVB1.1, J4.2, JP1.2 (B), PB_P1.24, PB_P2.13; also elsewhere on the board
+5VA: BBAI_P9.5, BBAI_P9.6, J3.2, JP1.1 (A), PB_P1.1
/LED_DS: BBAI_P9.30, ICE40HX8K-EVB1.23, PB_P2.25; also elsewhere on the board
/LED_SHCP: BBAI_P9.28, ICE40HX8K-EVB1.25, PB_P2.29; also elsewhere on the board
/LED_STCP: BBAI_P9.23, ICE40HX8K-EVB1.27, PB_P2.31; also elsewhere on the board
/MIC_CLK: BBAI_P9.11, ICE40HX8K-EVB1.21, PB_P2.24; also elsewhere on the board
/MIC_D0: BBAI_P8.44, ICE40HX8K-EVB1.5, PB_P1.36; also elsewhere on the board
/MIC_D1: BBAI_P8.41, ICE40HX8K-EVB1.7, PB_P1.33; also elsewhere on the board
/MIC_D2: BBAI_P8.42, ICE40HX8K-EVB1.9, PB_P2.32; also elsewhere on the board
/MIC_D3: BBAI_P8.39, ICE40HX8K-EVB1.11, PB_P2.30; also elsewhere on the board
/MIC_D4: BBAI_P8.40, ICE40HX8K-EVB1.13, PB_P1.31; also elsewhere on the board
/MIC_D5: BBAI_P8.37, ICE40HX8K-EVB1.15, PB_P2.34; also elsewhere on the board
/MIC_D6: BBAI_P8.38, ICE40HX8K-EVB1.17, PB_P2.28; also elsewhere on the board
/MIC_D7: BBAI_P8.36, ICE40HX8K-EVB1.19, PB_P1.29; also elsewhere on the board
/PB_USB_DM: J1.2 (D-), PB_P1.9
/PB_USB_DP: J1.3 (D+), PB_P1.11
/PB_USB_ID: J1.4 (ID), PB_P1.13
/PB_VBUS: J1.1 (VBUS), PB_P1.5, PB_P1.7
GND: BBAI_P8.1, BBAI_P8.2, BBAI_P9.1, BBAI_P9.2, BBAI_P9.43, BBAI_P9.44, BBAI_P9.45, BBAI_P9.46, H1.1, H2.1, H3.1, H4.1, ICE40HX8K-EVB1.2, ICE40HX8K-EVB1.4, ICE40HX8K-EVB1.8, J1.5 (GND), J1.6 (Shield), J3.1, J4.1, PB_P1.15, PB_P1.16, PB_P1.22, PB_P2.15, PB_P2.21; also elsewhere on the board

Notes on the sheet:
Power comes from host headers (BBAI, PB,...)
PocketBeagle Extra USB OTG Port
Optional External Power Supply
Leave open for Beagles, since their PMIC provides proper 5V_VOUT. Short if you want this cape to power the ICE40 EVB header.
PocketBeagle
BeagleBone AI
WARNING: There is no cutout for the ethernet connector! Need to use extension headers or a suitable additional cape.

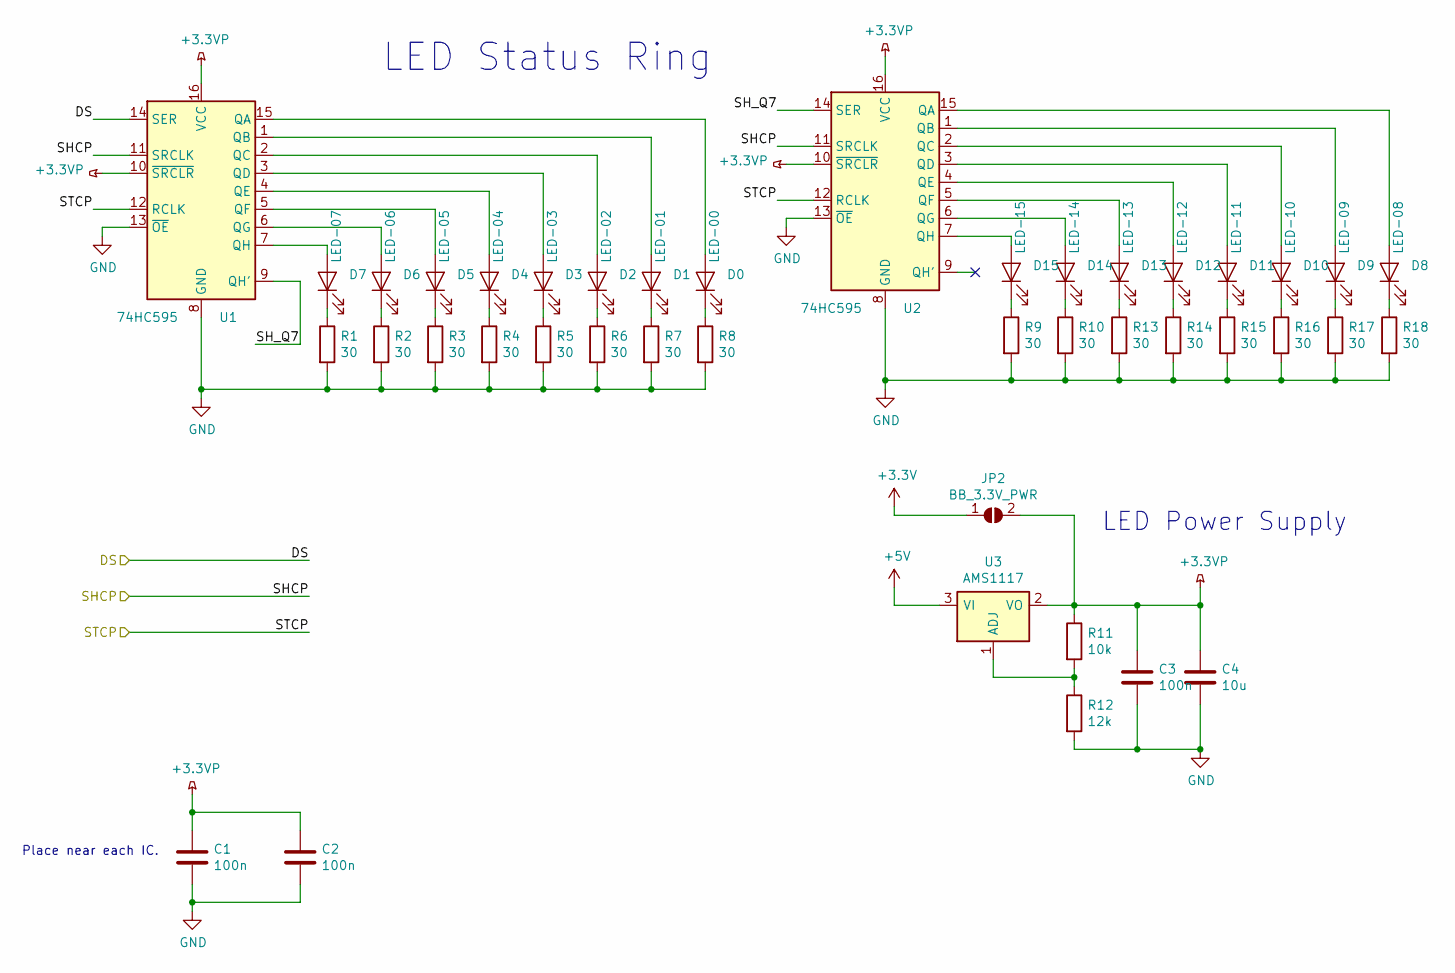
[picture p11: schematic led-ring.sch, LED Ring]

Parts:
C1, C2, C3: 100n; C_0805_2012Metric
C4: 10u; C_0805_2012Metric
D0: LED-00; LED_0805_2012Metric
D1: LED-01; LED_0805_2012Metric
D2: LED-02; LED_0805_2012Metric
D3: LED-03; LED_0805_2012Metric
D4: LED-04; LED_0805_2012Metric
D5: LED-05; LED_0805_2012Metric
D6: LED-06; LED_0805_2012Metric
D7: LED-07; LED_0805_2012Metric
D8: LED-08; LED_0805_2012Metric
D9: LED-09; LED_0805_2012Metric
D10: LED-10; LED_0805_2012Metric
D11: LED-11; LED_0805_2012Metric
D12: LED-12; LED_0805_2012Metric
D13: LED-13; LED_0805_2012Metric
D14: LED-14; LED_0805_2012Metric
D15: LED-15; LED_0805_2012Metric
JP2: BB_3.3V_PWR; SolderJumper-2_P1.3mm_Open_RoundedPad1.0x1.5mm
R1, R2, R3, R4, R5, R6, R7, R8, R9, R10, R13, R14, R15, R16, R17, R18: 30; R_0805_2012Metric
R11: 10k; R_0805_2012Metric
R12: 12k; R_0805_2012Metric
U1, U2: 74HC595; TSSOP-16_4.4x5mm_P0.65mm
U3: AMS1117; SOT-223-3_TabPin2

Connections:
+3.3VP: C1.1, C2.1, C3.1, C4.1, JP2.2 (B), R11.1, U1.10 (~SRCLR), U1.16 (VCC), U2.10 (~SRCLR), U2.16 (VCC), U3.2 (VO)
+3V3: JP2.1 (A); also elsewhere on the board
+5V: U3.3 (VI); also elsewhere on the board
/LED Ring/SH_Q7: U1.9 (QH'), U2.14 (SER)
/LED_DS: U1.14 (SER); also elsewhere on the board
/LED_SHCP: U1.11 (SRCLK), U2.11 (SRCLK); also elsewhere on the board
/LED_STCP: U1.12 (RCLK), U2.12 (RCLK); also elsewhere on the board
GND: C1.2, C2.2, C3.2, C4.2, R1.2, R2.2, R3.2, R4.2, R5.2, R6.2, R7.2, R8.2, R9.2, R10.2, R12.2, R13.2, R14.2, R15.2, R16.2, R17.2, R18.2, U1.8 (GND), U1.13 (~OE), U2.8 (GND), U2.13 (~OE); also elsewhere on the board
unnamed: D0.1 (K), R8.1
unnamed: D0.2 (A), U1.15 (QA)
unnamed: D1.1 (K), R7.1
unnamed: D1.2 (A), U1.1 (QB)
unnamed: D2.1 (K), R6.1
unnamed: D2.2 (A), U1.2 (QC)
unnamed: D3.1 (K), R5.1
unnamed: D3.2 (A), U1.3 (QD)
unnamed: D4.1 (K), R4.1
unnamed: D4.2 (A), U1.4 (QE)
unnamed: D5.1 (K), R3.1
unnamed: D5.2 (A), U1.5 (QF)
unnamed: D6.1 (K), R2.1
unnamed: D6.2 (A), U1.6 (QG)
unnamed: D7.1 (K), R1.1
unnamed: D7.2 (A), U1.7 (QH)
unnamed: D8.1 (K), R18.1
unnamed: D8.2 (A), U2.15 (QA)
unnamed: D9.1 (K), R17.1
unnamed: D9.2 (A), U2.1 (QB)
unnamed: D10.1 (K), R16.1
unnamed: D10.2 (A), U2.2 (QC)
unnamed: D11.1 (K), R15.1
unnamed: D11.2 (A), U2.3 (QD)
unnamed: D12.1 (K), R14.1
unnamed: D12.2 (A), U2.4 (QE)
unnamed: D13.1 (K), R13.1
unnamed: D13.2 (A), U2.5 (QF)
unnamed: D14.1 (K), R10.1
unnamed: D14.2 (A), U2.6 (QG)
unnamed: D15.1 (K), R9.1
unnamed: D15.2 (A), U2.7 (QH)
unnamed: R11.2, R12.1, U3.1 (ADJ)

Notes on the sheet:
LED Status Ring
LED Power Supply
Place near each IC.

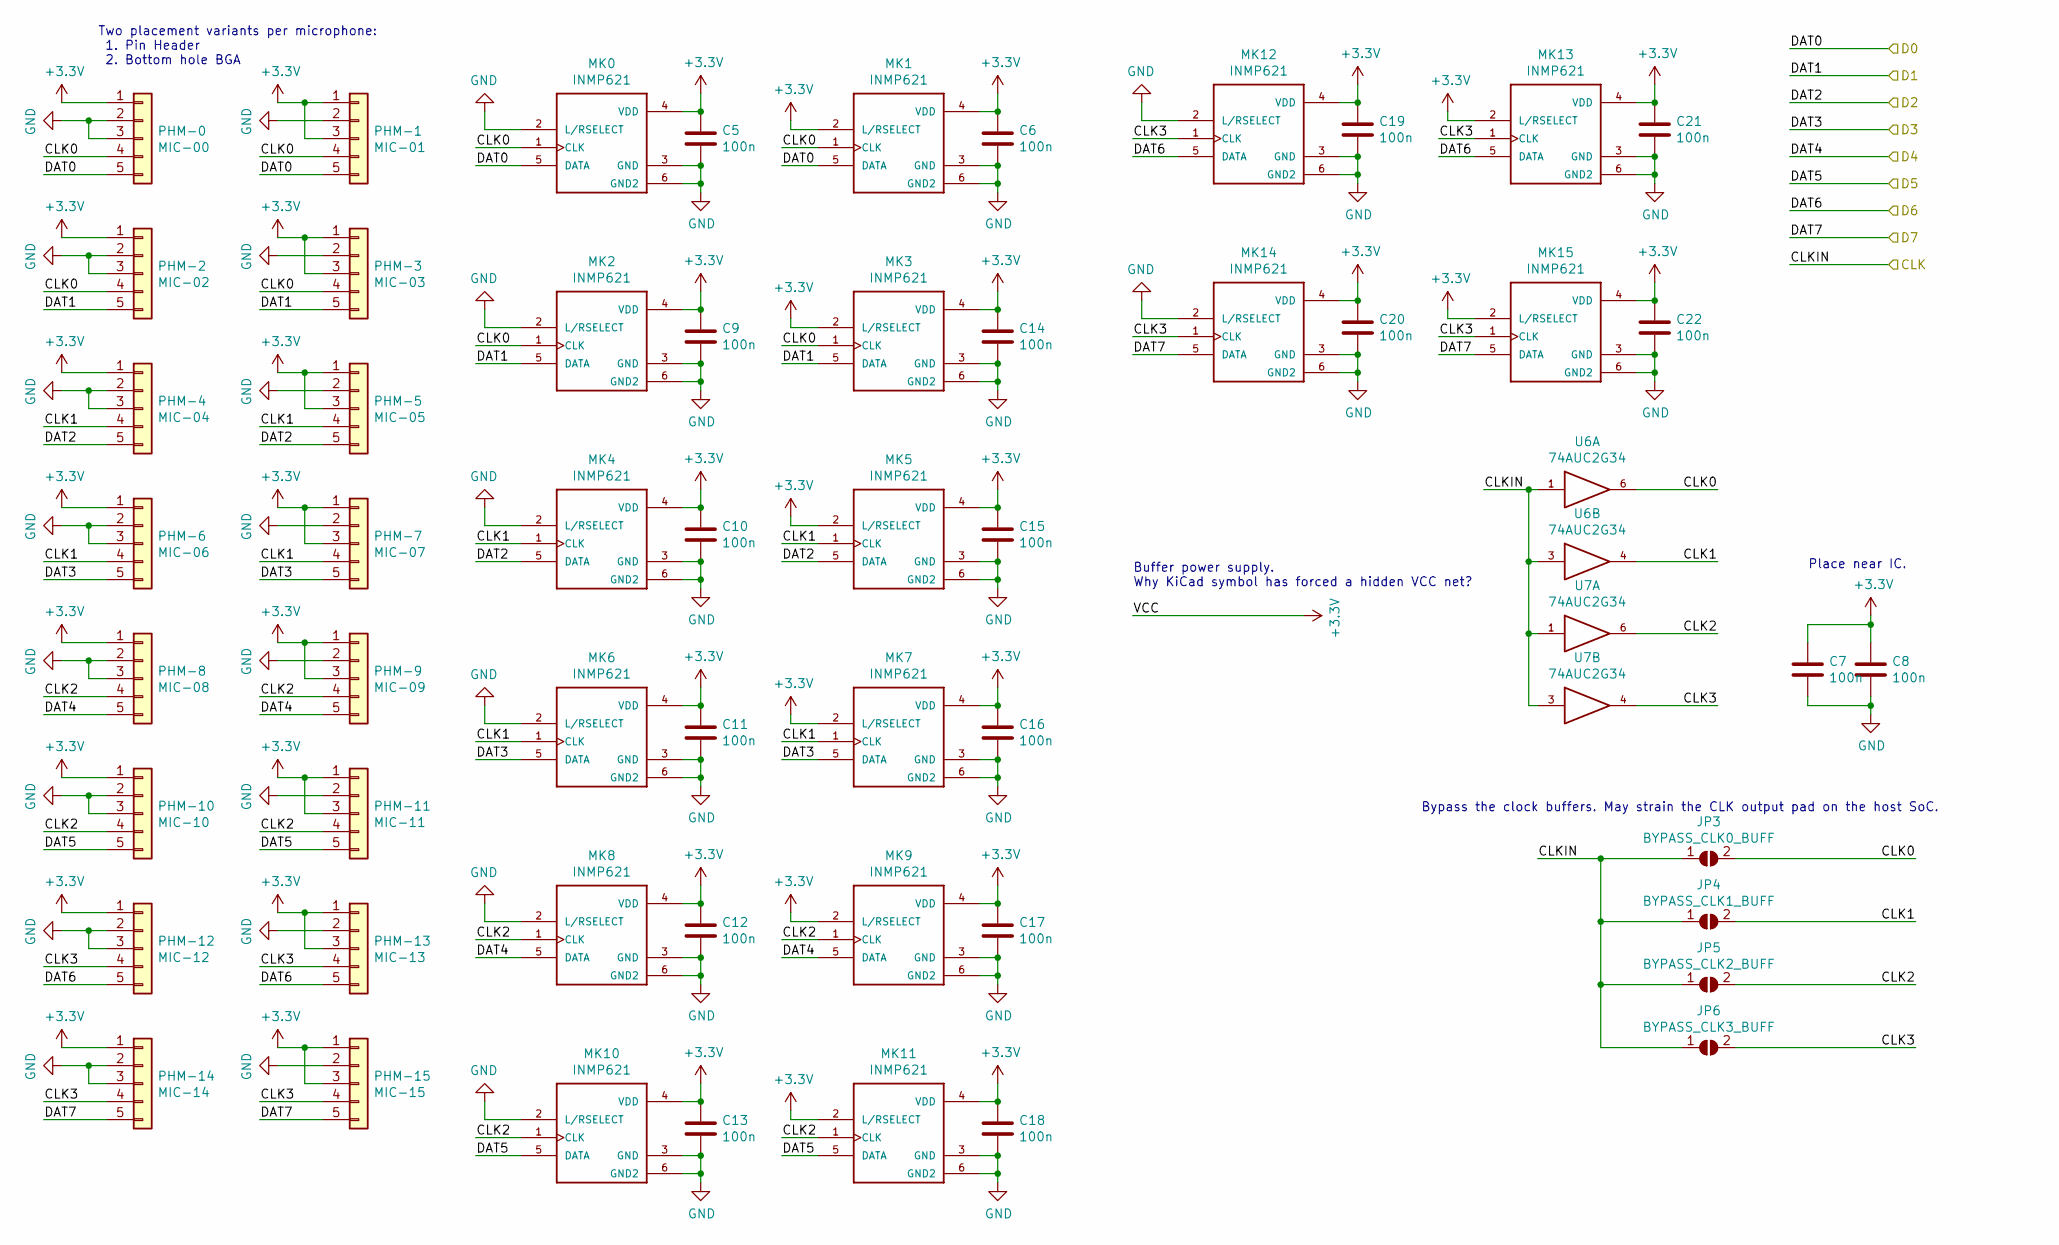
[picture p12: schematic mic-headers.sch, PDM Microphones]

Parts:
C5, C6, C7, C8, C9, C10, C11, C12, C13, C14, C15, C16, C17, C18, C19, C20, C21, C22: 100n; C_0805_2012Metric
JP3: BYPASS_CLK0_BUFF; SolderJumper-2_P1.3mm_Open_RoundedPad1.0x1.5mm
JP4: BYPASS_CLK1_BUFF; SolderJumper-2_P1.3mm_Open_RoundedPad1.0x1.5mm
JP5: BYPASS_CLK2_BUFF; SolderJumper-2_P1.3mm_Open_RoundedPad1.0x1.5mm
JP6: BYPASS_CLK3_BUFF; SolderJumper-2_P1.3mm_Open_RoundedPad1.0x1.5mm
MK0, MK1, MK2, MK3, MK4, MK5, MK6, MK7, MK8, MK9, MK10, MK11, MK12, MK13, MK14, MK15: INMP621; MK_INMP621
PHM-0: MIC-00; PinSocket_1x05_P2.54mm_Vertical
PHM-1: MIC-01; PinSocket_1x05_P2.54mm_Vertical
PHM-2: MIC-02; PinSocket_1x05_P2.54mm_Vertical
PHM-3: MIC-03; PinSocket_1x05_P2.54mm_Vertical
PHM-4: MIC-04; PinSocket_1x05_P2.54mm_Vertical
PHM-5: MIC-05; PinSocket_1x05_P2.54mm_Vertical
PHM-6: MIC-06; PinSocket_1x05_P2.54mm_Vertical
PHM-7: MIC-07; PinSocket_1x05_P2.54mm_Vertical
PHM-8: MIC-08; PinSocket_1x05_P2.54mm_Vertical
PHM-9: MIC-09; PinSocket_1x05_P2.54mm_Vertical
PHM-10: MIC-10; PinSocket_1x05_P2.54mm_Vertical
PHM-11: MIC-11; PinSocket_1x05_P2.54mm_Vertical
PHM-12: MIC-12; PinSocket_1x05_P2.54mm_Vertical
PHM-13: MIC-13; PinSocket_1x05_P2.54mm_Vertical
PHM-14: MIC-14; PinSocket_1x05_P2.54mm_Vertical
PHM-15: MIC-15; PinSocket_1x05_P2.54mm_Vertical
U6, U7: 74AUC2G34; SOT-23-6

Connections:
+3V3: C5.1, C6.1, C7.1, C8.1, C9.1, C10.1, C11.1, C12.1, C13.1, C14.1, C15.1, C16.1, C17.1, C18.1, C19.1, C20.1, C21.1, C22.1, MK0.4 (VDD), MK1.2 (L/RSELECT), MK1.4 (VDD), MK2.4 (VDD), MK3.2 (L/RSELECT), MK3.4 (VDD), MK4.4 (VDD), MK5.2 (L/RSELECT), MK5.4 (VDD), MK6.4 (VDD), MK7.2 (L/RSELECT), MK7.4 (VDD), MK8.4 (VDD), MK9.2 (L/RSELECT), MK9.4 (VDD), MK10.4 (VDD), MK11.2 (L/RSELECT), MK11.4 (VDD), MK12.4 (VDD), MK13.2 (L/RSELECT), MK13.4 (VDD), MK14.4 (VDD), MK15.2 (L/RSELECT), MK15.4 (VDD), PHM-0.1, PHM-1.1, PHM-1.3, PHM-2.1, PHM-3.1, PHM-3.3, PHM-4.1, PHM-5.1, PHM-5.3, PHM-6.1, PHM-7.1, PHM-7.3, PHM-8.1, PHM-9.1, PHM-9.3, PHM-10.1, PHM-11.1, PHM-11.3, PHM-12.1, PHM-13.1, PHM-13.3, PHM-14.1, PHM-15.1, PHM-15.3, U6.5 (VCC), U7.5 (VCC); also elsewhere on the board
/MIC_CLK: JP3.1 (A), JP4.1 (A), JP5.1 (A), JP6.1 (A), U6.1, U6.3, U7.1, U7.3; also elsewhere on the board
/MIC_D0: MK0.5 (DATA), MK1.5 (DATA), PHM-0.5, PHM-1.5; also elsewhere on the board
/MIC_D1: MK2.5 (DATA), MK3.5 (DATA), PHM-2.5, PHM-3.5; also elsewhere on the board
/MIC_D2: MK4.5 (DATA), MK5.5 (DATA), PHM-4.5, PHM-5.5; also elsewhere on the board
/MIC_D3: MK6.5 (DATA), MK7.5 (DATA), PHM-6.5, PHM-7.5; also elsewhere on the board
/MIC_D4: MK8.5 (DATA), MK9.5 (DATA), PHM-8.5, PHM-9.5; also elsewhere on the board
/MIC_D5: MK10.5 (DATA), MK11.5 (DATA), PHM-10.5, PHM-11.5; also elsewhere on the board
/MIC_D6: MK12.5 (DATA), MK13.5 (DATA), PHM-12.5, PHM-13.5; also elsewhere on the board
/MIC_D7: MK14.5 (DATA), MK15.5 (DATA), PHM-14.5, PHM-15.5; also elsewhere on the board
/Microphone Headers/CLK0: JP3.2 (B), MK0.1 (CLK), MK1.1 (CLK), MK2.1 (CLK), MK3.1 (CLK), PHM-0.4, PHM-1.4, PHM-2.4, PHM-3.4, U6.6
/Microphone Headers/CLK1: JP4.2 (B), MK4.1 (CLK), MK5.1 (CLK), MK6.1 (CLK), MK7.1 (CLK), PHM-4.4, PHM-5.4, PHM-6.4, PHM-7.4, U6.4
/Microphone Headers/CLK2: JP5.2 (B), MK8.1 (CLK), MK9.1 (CLK), MK10.1 (CLK), MK11.1 (CLK), PHM-8.4, PHM-9.4, PHM-10.4, PHM-11.4, U7.6
/Microphone Headers/CLK3: JP6.2 (B), MK12.1 (CLK), MK13.1 (CLK), MK14.1 (CLK), MK15.1 (CLK), PHM-12.4, PHM-13.4, PHM-14.4, PHM-15.4, U7.4
GND: C5.2, C6.2, C7.2, C8.2, C9.2, C10.2, C11.2, C12.2, C13.2, C14.2, C15.2, C16.2, C17.2, C18.2, C19.2, C20.2, C21.2, C22.2, MK0.2 (L/RSELECT), MK0.3 (GND), MK0.6 (GND2), MK1.3 (GND), MK1.6 (GND2), MK2.2 (L/RSELECT), MK2.3 (GND), MK2.6 (GND2), MK3.3 (GND), MK3.6 (GND2), MK4.2 (L/RSELECT), MK4.3 (GND), MK4.6 (GND2), MK5.3 (GND), MK5.6 (GND2), MK6.2 (L/RSELECT), MK6.3 (GND), MK6.6 (GND2), MK7.3 (GND), MK7.6 (GND2), MK8.2 (L/RSELECT), MK8.3 (GND), MK8.6 (GND2), MK9.3 (GND), MK9.6 (GND2), MK10.2 (L/RSELECT), MK10.3 (GND), MK10.6 (GND2), MK11.3 (GND), MK11.6 (GND2), MK12.2 (L/RSELECT), MK12.3 (GND), MK12.6 (GND2), MK13.3 (GND), MK13.6 (GND2), MK14.2 (L/RSELECT), MK14.3 (GND), MK14.6 (GND2), MK15.3 (GND), MK15.6 (GND2), PHM-0.2, PHM-0.3, PHM-1.2, PHM-2.2, PHM-2.3, PHM-3.2, PHM-4.2, PHM-4.3, PHM-5.2, PHM-6.2, PHM-6.3, PHM-7.2, PHM-8.2, PHM-8.3, PHM-9.2, PHM-10.2, PHM-10.3, PHM-11.2, PHM-12.2, PHM-12.3, PHM-13.2, PHM-14.2, PHM-14.3, PHM-15.2, U6.2 (GND), U7.2 (GND); also elsewhere on the board

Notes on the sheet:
Bypass the clock buffers. May strain the CLK output pad on the host SoC.
Place near IC.
Two placement variants per microphone: 1. Pin Header 2. Bottom hole BGA
Buffer power supply. Why KiCad symbol has forced a hidden VCC net?

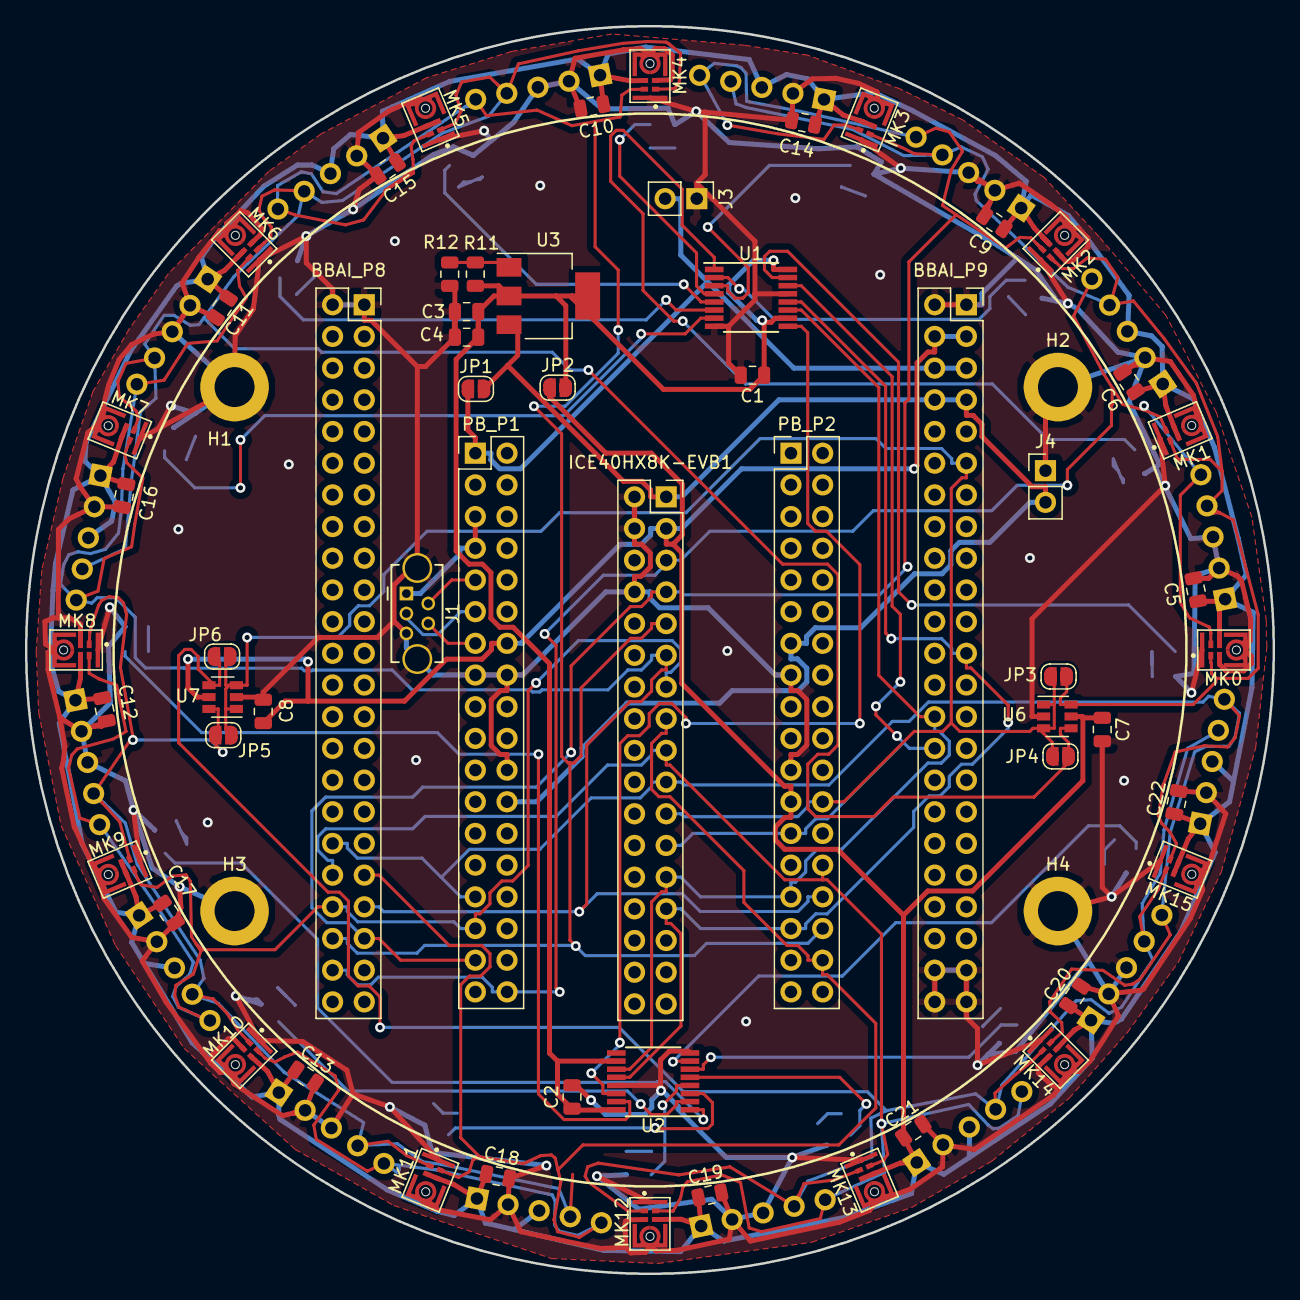
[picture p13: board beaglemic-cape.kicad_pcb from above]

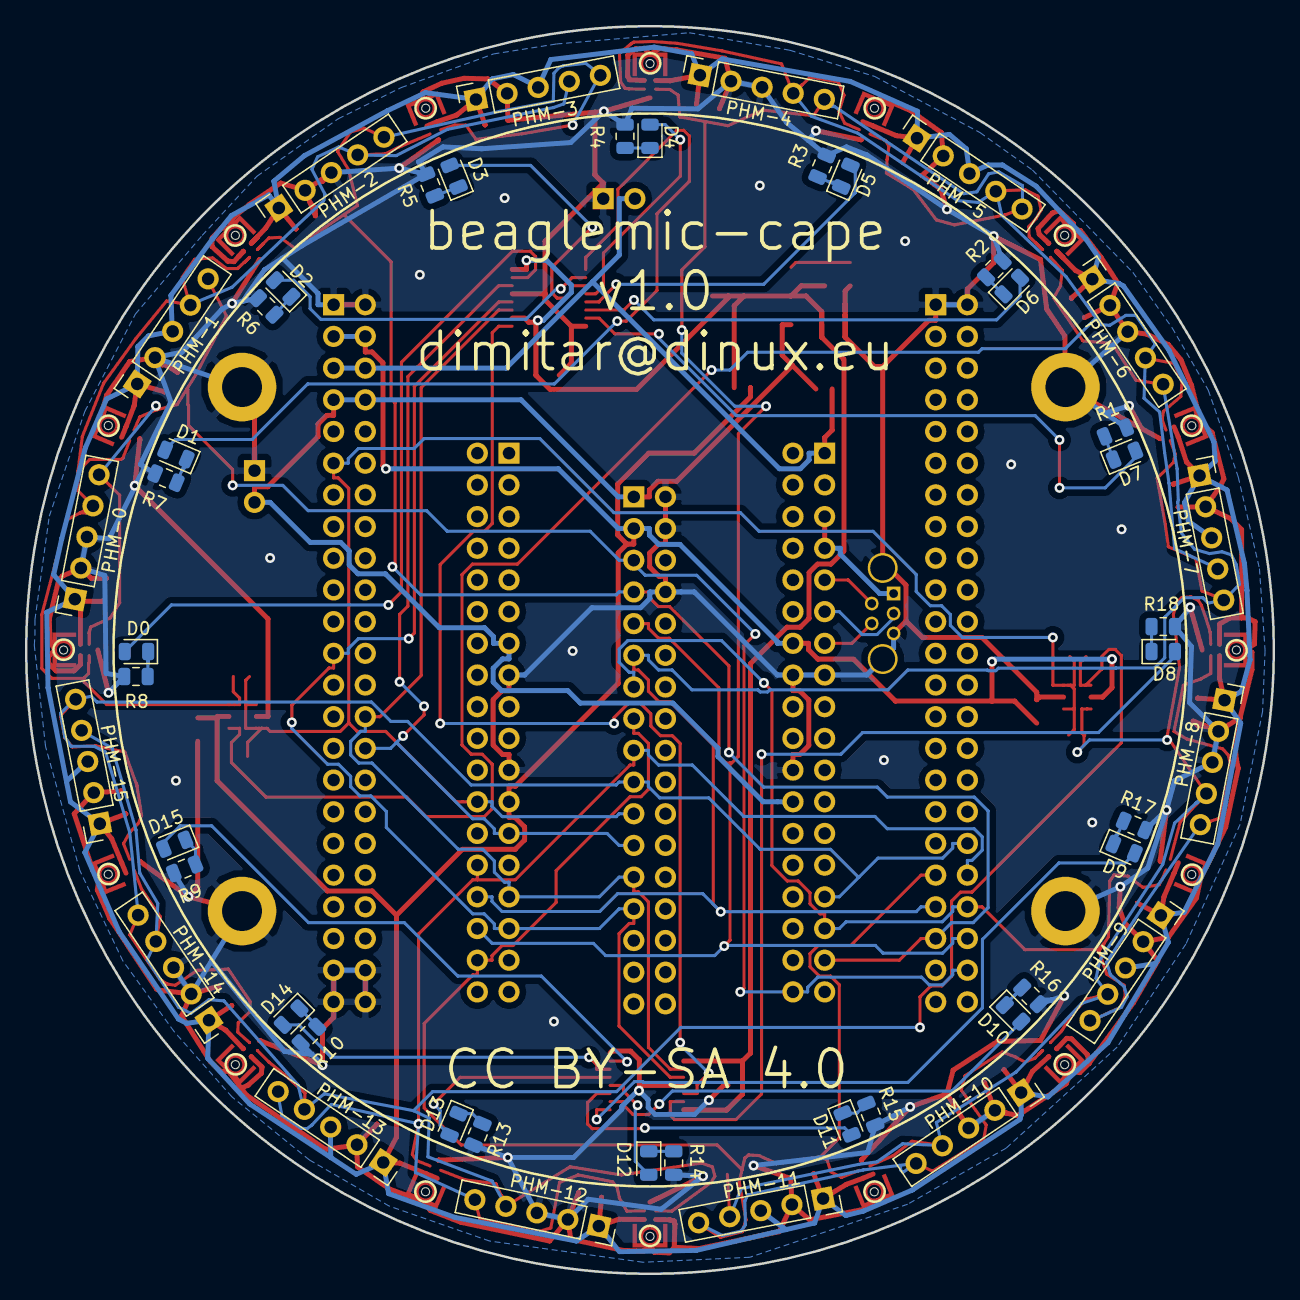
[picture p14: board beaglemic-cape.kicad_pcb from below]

Board: 2 copper layers, 100.0 x 100.0 mm, 111 parts (48 on the bottom side), 59 nets.

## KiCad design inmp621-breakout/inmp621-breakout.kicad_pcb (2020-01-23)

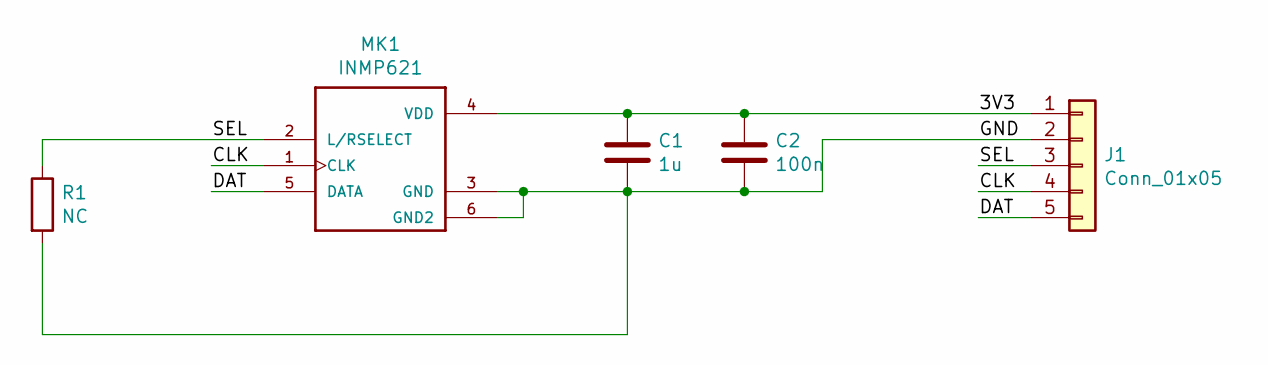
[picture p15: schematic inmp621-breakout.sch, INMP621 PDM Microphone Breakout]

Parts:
C1: 1u; C_0805_2012Metric
C2: 100n; C_0805_2012Metric
J1: Conn_01x05; PinHeader_1x05_P2.54mm_Vertical
MK1: INMP621; MK_INMP621
R1: NC; R_0805_2012Metric

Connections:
/3V3: C1.1, C2.1, J1.1, MK1.4 (VDD)
/CLK: J1.4, MK1.1 (CLK)
/DAT: J1.5, MK1.5 (DATA)
/GND: C1.2, C2.2, J1.2, MK1.3 (GND), MK1.6 (GND2), R1.2
/SEL: J1.3, MK1.2 (L/RSELECT), R1.1

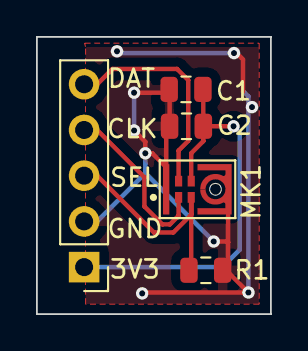
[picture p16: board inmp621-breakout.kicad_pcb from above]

Board: 2 copper layers, 13.0 x 15.4 mm, 5 parts (0 on the bottom side), 5 nets.

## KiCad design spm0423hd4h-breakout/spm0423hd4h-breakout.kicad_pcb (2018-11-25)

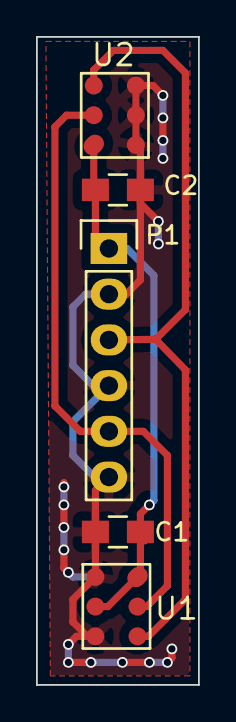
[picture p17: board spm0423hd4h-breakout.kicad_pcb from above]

Board: 2 copper layers, 9.0 x 36.0 mm, 5 parts (0 on the bottom side), 4 nets.

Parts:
C1, C2: 100n; C_0805_HandSoldering
P1: CONN_01X06; Pin_Header_Straight_1x06
U1: MIC1; BGA_6
U2: MIC0; BGA_6

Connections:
/CLK: P1.3, U1.4, U2.4
/D: P1.5, U1.5, U2.5
GND: C1.2, C2.2, P1.2, P1.4, P1.6, U1.1, U1.3, U2.1, U2.2, U2.3
VDD: C1.1, C2.1, P1.1, U1.2, U1.6, U2.6

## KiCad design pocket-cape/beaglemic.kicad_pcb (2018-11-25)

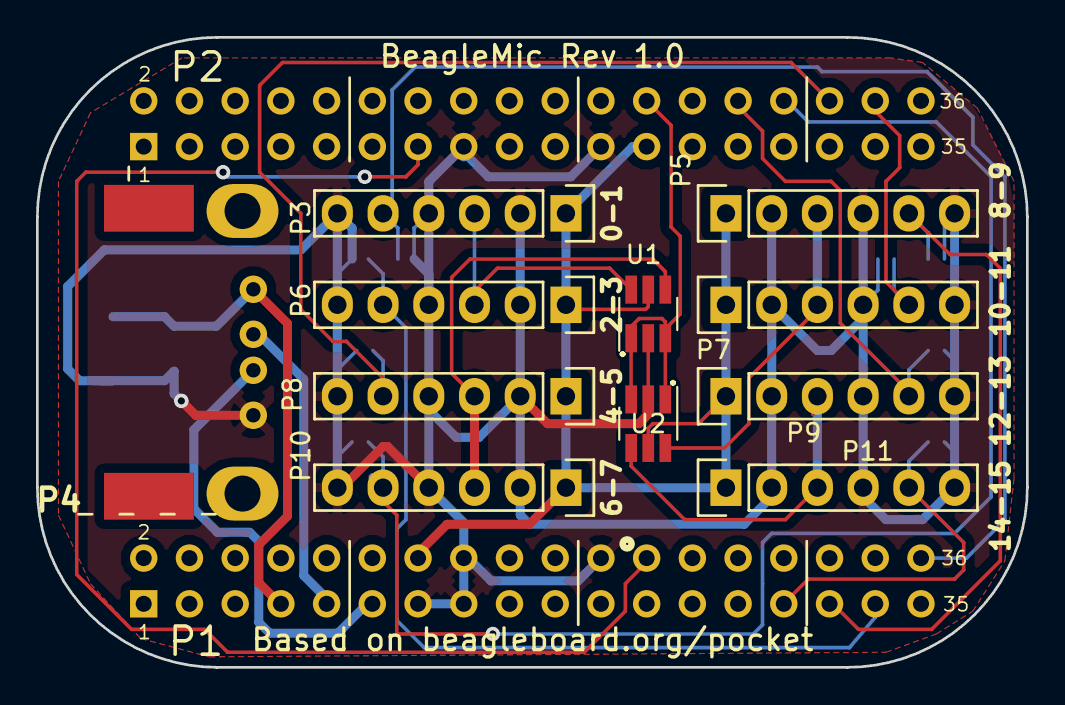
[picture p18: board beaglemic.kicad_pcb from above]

Board: 2 copper layers, 55.0 x 35.0 mm, 23 parts (0 on the bottom side), 19 nets.

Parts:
C1: 100n; C_0805_HandSoldering
C2: 1u; SMD-1210_Pol
P1, P2: TH-2X18-(35MIL-DIA)-W_O-SILK
P3, P5, P6, P7, P8, P9, P10, P11: CONN_01X06; Pin_Header_Straight_1x06
P4: USB_A; USB-3.5mm(TERES)
R1, R2, R3, R4, R5, R6, R7, R8: 10k; R_0402
U1, U2: 74AUC2G34; SOT-23-6_Handsoldering

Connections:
/(U1.A1)PWM0A: P1.36, P3.5, R1.2
/(U1.A2)PRU-0.1: P1.33, P6.5, R3.2
/(U1.A3)PRU-0.4: P1.31, P5.5, R2.2
/(U1.B1)PRU-0.3: P2.30, P10.5, R7.2
/(U1.B2)PRU-0.2: P2.32, P8.5, R5.2
/(U1.B3)PRU-0.5: P2.34, P7.5, R4.2
/(U1.C3)PRU-0.6: P2.28, P9.5, R6.2
/(U1.C4)PRU-0.7: P1.29, P11.5, R8.2
/(U1.L15)USB1.D+: P1.11, P4.3
/(U1.L16)USB1.D-: P1.9, P4.2
/(U1.P6): P2.24, U1.1, U1.3, U2.1, U2.3
/MIC_CLK_0_3: P3.3, P6.3, U1.6
/MIC_CLK_4_7: P8.3, P10.3, U1.4
/MIC_CLK_8_11: P5.3, P7.3, U2.6
/MIC_CLK_12_15: P9.3, P11.3, U2.4
GND: C1.2, C2.2, P1.13, P1.15, P1.16, P1.22, P2.15, P2.21, P3.2, P3.4, P3.6, P4.4, P5.2, P5.4, P5.6, P6.2, P6.4, P6.6, P7.2, P7.4, P7.6, P8.2, P8.4, P8.6, P9.2, P9.4, P9.6, P10.2, P10.4, P10.6, P11.2, P11.4, P11.6, R1.1, R2.1, R3.1, R4.1, R5.1, R6.1, R7.1, R8.1, U1.2, U2.2
SYS_5V: P1.24, P2.13
USB_DC: C1.1, C2.1, P1.7, P4.1
VDD_3V3B: P1.14, P2.23, P3.1, P5.1, P6.1, P7.1, P8.1, P9.1, P10.1, P11.1, U1.5, U2.5

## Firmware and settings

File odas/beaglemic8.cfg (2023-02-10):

# Configuration file for BeagleMic circular sound USB card
# For 24bps/8channels mode of operation.

version = "2.1";

# Raw

raw: 
{

    fS = 24000;
    hopSize = 128;
    nBits = 32;
    nChannels = 8; 

    # Input with raw signal from microphones
    interface: {
        type = "soundcard_name";
	devicename = "hw:CARD=BeagleMic";
    }

}

# Mapping

mapping:
{

    map: (1, 2, 3, 4, 5, 6, 7, 8);

}

# General

general:
{
    
    epsilon = 1E-20;

    size: 
    {
        hopSize = 128;
        frameSize = 256;
    };
    
    samplerate:
    {
        mu = 16000;
        sigma2 = 0.01;
    };

    speedofsound:
    {
        mu = 343.0;
        sigma2 = 25.0;
    };

    mics = (
        
        # Microphone 0
        { 
            mu = ( -0.046, +0.000, +0.000 ); 
            sigma2 = ( +0.000, +0.000, +0.000, +0.000, +0.000, +0.000, +0.000, +0.000, +0.000 );
            direction = ( +0.000, +0.000, +1.000 );
            angle = ( 90.0, 100.0 );
        },

        # Microphone 1
        { 
            mu = ( -0.032527, +0.032527, +0.000 ); 
            sigma2 = ( +0.000, +0.000, +0.000, +0.000, +0.000, +0.000, +0.000, +0.000, +0.000 );
            direction = ( +0.000, +0.000, +1.000 );
            angle = ( 90.0, 100.0 );
        },

        # Microphone 2
        { 
            mu = ( -0.000000, +0.046000, +0.000 ); 
            sigma2 = ( +0.000, +0.000, +0.000, +0.000, +0.000, +0.000, +0.000, +0.000, +0.000 );
            direction = ( +0.000, +0.000, +1.000 );
            angle = ( 90.0, 100.0 );
        },

        # Microphone 3
        { 
            mu = ( 0.032527, 0.032527, +0.000 ); 
            sigma2 = ( +0.000, +0.000, +0.000, +0.000, +0.000, +0.000, +0.000, +0.000, +0.000 );
            direction = ( +0.000, +0.000, +1.000 );
            angle = ( 90.0, 100.0 );
        },

        # Microphone 4
        { 
            mu = ( 0.046000, 0.000000, +0.000 ); 
            sigma2 = ( +0.000, +0.000, +0.000, +0.000, +0.000, +0.000, +0.000, +0.000, +0.000 );
            direction = ( +0.000, +0.000, +1.000 );
            angle = ( 90.0, 100.0 );        
        },

        # Microphone 5
        { 
            mu = ( 0.032527, -0.032527, +0.000 ); 
            sigma2 = ( +0.000, +0.000, +0.000, +0.000, +0.000, +0.000, +0.000, +0.000, +0.000 );
            direction = ( +0.000, +0.000, +1.000 );
            angle = ( 90.0, 100.0 );        
        },

        # Microphone 6
        { 
            mu = ( 0.000000, -0.046000, +0.000 ); 
            sigma2 = ( +0.000, +0.000, +0.000, +0.000, +0.000, +0.000, +0.000, +0.000, +0.000 );
            direction = ( +0.000, +0.000, +1.000 );
            angle = ( 90.0, 100.0 );
        },

        # Microphone 7
        { 
            mu = ( -0.032527, -0.032527, +0.000 ); 
            sigma2 = ( +0.000, +0.000, +0.000, +0.000, +0.000, +0.000, +0.000, +0.000, +0.000 );
            direction = ( +0.000, +0.000, +1.000 );
            angle = ( 90.0, 100.0 );
        }
    );

    # Spatial filters to include only a range of direction if required
    # (may be useful to remove false detections from the floor, or
    # limit the space search to a restricted region)
    spatialfilters = (

        {

            direction = ( +0.000, +0.000, +1.000 );
            angle = (90.0, 95.0);

        }

    );   

    nThetas = 181;
    gainMin = 0.25;

};

# Stationnary noise estimation

sne:
{
    
    b = 3;
    alphaS = 0.1;
    L = 150;
    delta = 3.0;
    alphaD = 0.1;

}

# Sound Source Localization

ssl:
{

    nPots = 4;
    nMatches = 10;
    probMin = 0.5;
    nRefinedLevels = 1;
    interpRate = 4;

    # Number of scans: level is the resolution of the sphere
    # and delta is the size of the maximum sliding window
    # (delta = -1 means the size is automatically computed)
    scans = (
        { level = 2; delta = -1; },
        { level = 4; delta = -1; }
    );

    # Output to export potential sources
    potential: {

        format = "undefined";

        interface: {
            type = "blackhole";
        };

    };

};

# Sound Source Tracking
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

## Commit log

2018-11-25 Add BeagleMic project
    [beaglemic-B.Mask.gbs, beaglemic-B.Paste.gbp, beaglemic-B.SilkS.gbo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]
2019-09-22 beaglemic: Update documentation
    Cape and PDM breakout boards have been validated, and errata has been written.
    So update README to remove the "untested" reference.
2020-01-04 beaglemic: INMP621 breakout - rc1
    Initial release for the INMP621 PDM microphone breakout board.
    WARNING - I have not validated it yet!
    [INMP621--3DModel-STEP-56544.STEP, inmp621-breakout.kicad_pcb, inmp621-breakout.sch]
2020-01-04 beaglemic: BeagleMic Cape - rc1
    Cape allowing to connect 16 PDM breakout boards to either:
    * PocketBeagle
    * BeagleBone AI
    * iCE40HX8K-EVB
    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
    [INMP621--3DModel-STEP-56544.STEP, beaglemic-cape.kicad_pcb, beaglemic-cape.sch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]
2020-01-04 beaglemic: Validate LED strip on PocketBeagle
2020-01-06 Add pocketbeagle LED strip connections
2020-01-19 beaglemic-cape: Shrink PCB to 100x100mm
    Let's keep the PCB in the hobby price range.
    Version 1.0-rc2
    TODO: Route me!
    [beaglemic-cape.kicad_pcb, beaglemic-cape.sch, led-ring.sch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]
2020-01-23 inmp621-breakout: Minor silkscreen fixes
    [inmp621-breakout.kicad_pcb]
2020-01-26 beaglemic-cape: Route PCB
    WARNING - NOT TESTED YET!
    [beaglemic-cape.kicad_pcb, beaglemic-cape.sch, led-ring.sch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]
2020-02-22 inmp621-breakout: Bump version
    PCB was validated, so set version to 1.0.
    [inmp621-breakout.sch]
2020-02-22 Deprecate pocket-cape and spm0423hd4h-breakout
    Those designs were validated to work correctly. But they proved
    difficult to assemble due to the multiple wires. Also, fitting
    two microphones on a single PCB puts too much constraints on the
    mechanical design.
    [beaglemic-B.Mask.gbs, beaglemic-B.Paste.gbp, beaglemic-B.SilkS.gbo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]
2020-04-05 Add pinctrl config for PB led strip
2020-04-05 beaglemic-cape: Minor documentation updates
    [beaglemic-cape.sch, led-ring.sch, mic-headers.sch]
2020-05-17 pru: Fix channel order
    Sampling just before rising edge is for MIC0 (grounded RSELECT).
    MIC1 is sampled on or before falling edge.
2020-05-17 Gradute from testing phase
    Cape with soldered microphones was tested on BBAI and PocketBeagle.
2020-05-30 PRU1: Always acknowledge peer interrupt
    Even if stream is disabled, let's acknowledge the peer PRU0
    interrupt.
2020-05-30 PRU0: Reset microphone when switching modes
    This fixes occasional increased noise in some channels
    when switching between 16ch and 8ch modes.
2020-10-11 g_uac: Add compand filter
2020-10-31 Switch license of my own PRU work to BSD-2-Clause
2020-10-31 Remove deprecated boards
    [beaglemic-B.Mask.gbs, beaglemic-B.Paste.gbp, beaglemic-B.SilkS.gbo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]
2021-01-01 buildroot: Switch to simple gain
    Drop the compand operation and instead do a simple gain for the audio
    data we send over USB.
    It turned out that:
    - SOX compand (predictably) adds large latency.
    - It is difficult to tune the compand filter parameters.
    So instead let's defer this complex job to the user (e.g. ODAS).
2021-01-28 buildroot: Add COPYING to package beaglemic-driver
2023-02-10 Add ODAS configuration
    [beaglemic8.cfg]

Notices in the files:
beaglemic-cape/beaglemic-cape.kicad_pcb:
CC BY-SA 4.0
